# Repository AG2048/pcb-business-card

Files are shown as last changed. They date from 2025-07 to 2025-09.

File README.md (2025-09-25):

# pcb-business-card
Business card made using functional PCBs

Latest Revision: V1 (2025)

# Major Revisions:
## V1 (2025)
- Initial release of the PCB business card design.
- Design functions fully wirelessly, no need for any wired connections during operation. Maintains a slim profile (0.8mm thick PCB, with components on one side only).
- PCB dimensions: 85.6mm x 53.98mm (standard credit card size).
- Qi Wireless charging support -- Utilizes BQ51013B Qi Wireless Power Receiver IC to allow for wireless powering of the PCB business card in 5V 1A.
- NFC Tag support -- Utilizes ST25DV64K NFC Tag to allow for wirelessly programming of the RGB LED Matrix Display, while also allowing users to tap the card on their phone to load my website [andygong.com](https://andygong.com).
- RGB LED Matrix / Array Display -- Utilizes a 6x12 RGB LED Matrix of SK6805-EC15 LEDs to allow for colorful display of patterns that can be controlled by an on-board ATtiny84A microcontroller.
- The QR code on the back of the card can be scanned to load [andygong.com](https://andygong.com) as well.

PCB manufactured by [JLCPCB](https://jlcpcb.com/). Prototype boards assembled by [JLCPCB SMT Assembly Service](https://jlcpcb.com/smt-assembly). Further component sourcing and assembly done by myself.

### Images

#### Renders
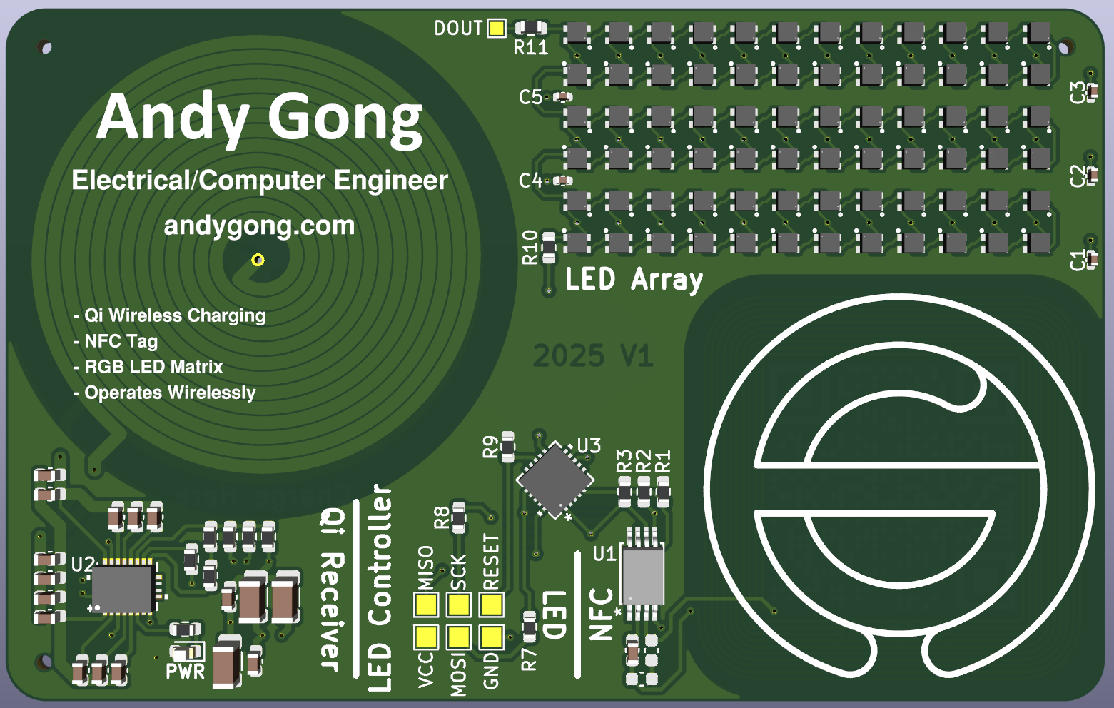
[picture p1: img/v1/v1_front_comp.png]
V1 Front

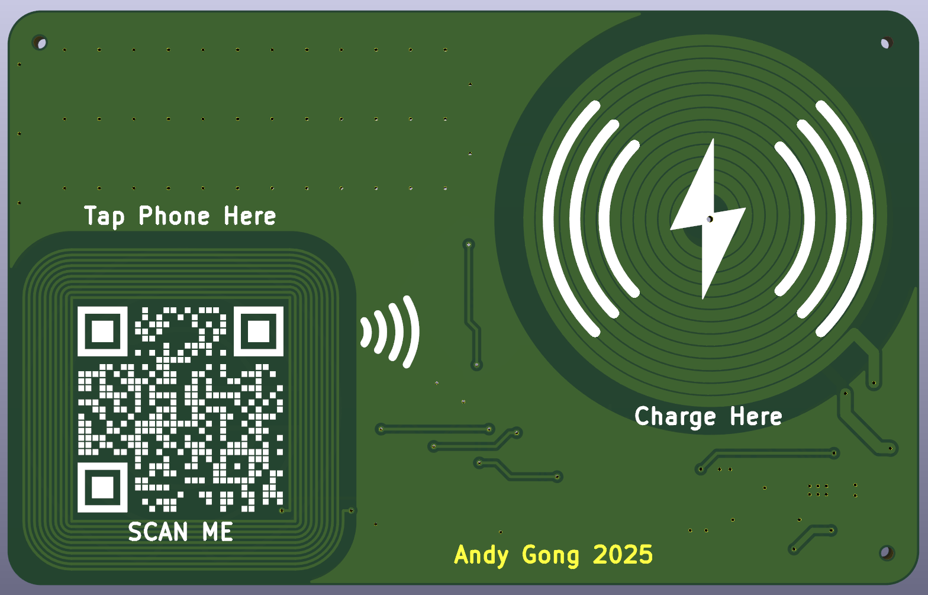
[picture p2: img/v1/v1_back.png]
V1 Back

#### Manufactured Board
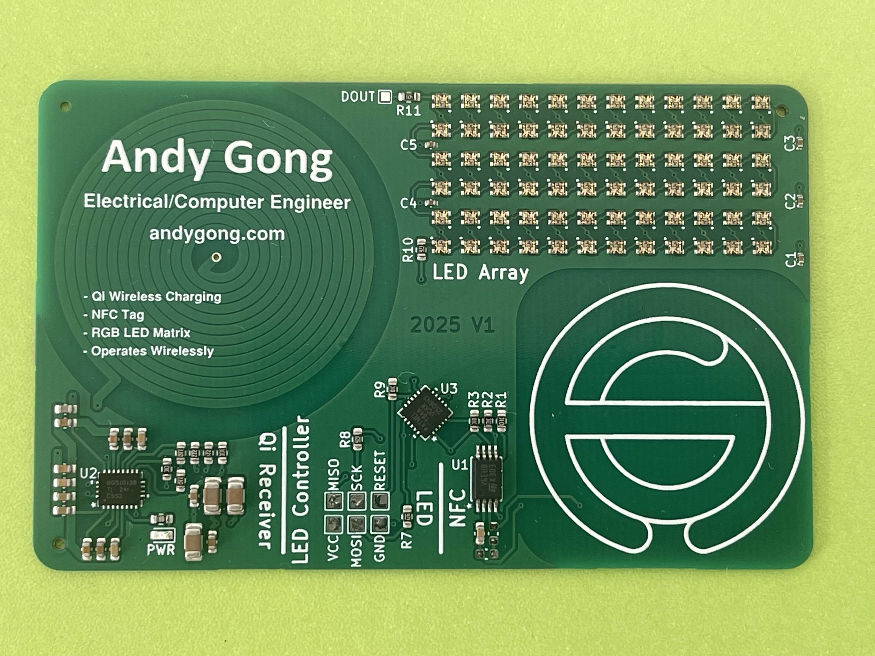
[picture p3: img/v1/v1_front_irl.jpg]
V1 Manufactured Front

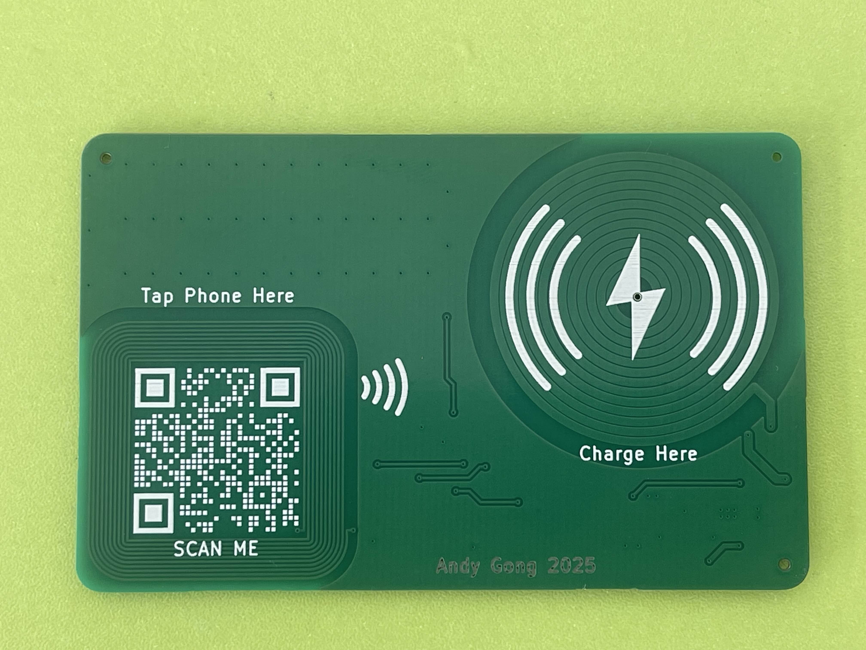
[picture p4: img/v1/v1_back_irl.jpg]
V1 Manufactured Back

#### Early Code Testing
`img/v1/v1_early_test.mov` -- Demonstrates simple patterns on the RGB LED Matrix, with an "Among Us" pixel art pattern shown at the end, which is data sent to the NFC tag by phone, and read by the ATTiny84 using I2C. The code snapshot is [HERE](https://github.com/AG2048/pcb-business-card/commit/e9710af22d912196d3559052da2425deacd2d185)

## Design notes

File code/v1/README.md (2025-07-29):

# V1 Code

This directory contains the code for the AG Business Card V1. This code is to be run on the ATTiny84 microcontroller on the PCB. It reads the ST25DV64K NFC tag for display patterns and displays them on the 6x12 RGB LED matrix.

## Requirements
- ISP Programmer (Used Arduino Uno as ISP)
- [ATTinyCore](https://github.com/SpenceKonde/ATTinyCore)
  - [Wire](https://github.com/SpenceKonde/ATTinyCore/tree/v2.0.0-devThis-is-the-head-submit-PRs-against-this/avr/libraries/Wire) included with ATTinyCore, this allows the use of the hardware I2C on the ATTiny84.
  - [tinyNeoPixel_Static](https://github.com/SpenceKonde/ATTinyCore/tree/v2.0.0-devThis-is-the-head-submit-PRs-against-this/avr/libraries/tinyNeoPixel_Static) for controlling the RGB LED matrix. The static version is used

## Pins
The pinout for ATTiny84 can be found in the [ATTinyCore documentation](https://github.com/SpenceKonde/ATTinyCore/blob/v2.0.0-devThis-is-the-head-submit-PRs-against-this/avr/extras/ATtiny_x4.md). 

The most relevant pin is the LED pin, defined as `LED_PIN` in the code, which is connected to pin 10 of the ATTiny84. This pin is used to control the RGB LED matrix. 

When using the `tinyNeoPixel_Static` library, I configured the bootloader to use PORT B (which is where pin 10 is located). 

The I2C pins uses the standard SDA and SCL pins, so `Wire.begin()` will automatically use the correct pins.

## LED Matrix
The `tinyNeoPixel_Static` library is used to control the RGB LED matrix. This library uses a static array of bytes to store the pixel data in `GRB888` format. The pixels can be modified by setting corresponding values in the `pixel_data` array.

After some preliminary tests, the brightness of each colour of the RGB LEDs is set to be capped at 15 (0xF) to prevent:
1. Excess power draw -- as a "full white" test of max brightness (255) caused the LED matrix to appear red / orange (not enough power supply to light up the green and blue LEDs sufficiently).
2. Excess brightness -- at 255, the LEDs' brightness can be "blinding", and regular phone cameras would likely just capture a "white blur" instead of individual pixels. 

This setup can also save memory. Since a `GRB888` array for 72 pixels takes up 216 bytes out of the total 512 bytes RAM on ATTiny84, and if the brightness is capped at 15 (only 4 bits per channel), the memory requirement can effectively be halved. 

### tinyNeoPixel_Static Modifications
To accomodate a reduced-sized pixels array, the original `tinyNeoPixel_Static` library can no longer be used. 
1. The array now stores GRBGRBGRBGRB... tightly in GRB444 format (Meaning two neighbouring pixels may share bytes)
2. The `show()` function's assembly code is modified to default display `0` for the higher 4 bits. 
   - Adding 4 extra 0 writes in front of bit 7 and bit 3 makes the assembly code too long that the relative jump at the end of each byte write cannot reach the beginning of the program. (64 instructions limit per jump)
   - Broken the code into a write upper bits, write lower bits, and two separate write-zero functions. They are arranged in: WRITE_UPPER -> WRITE_ZERO_TO_LOWER -> WRITE_ZERO_TO_UPPER -> WRITE_LOWER.
   - The program starts the write-zero that jumps to write upper bits. Then it proceeds to the write-zero that jumps to write lower bits. Finally, it jumps back to the write zero that jumps to write upper bits again. The program loops in a sort of "zig-zag" pattern.
   - This breaks the jumps into smaller 50-ish instructions jumps, allowing the assembly code to function within the timing constraints of the LEDs, since there is not a lot of free instructions left to fit every bit write within 10 cycles. 

A custom leds_set_pixel_color function is used to set the pixel color in the `pixel_data` array. This function takes the x and y coordinates of the pixel, and the red, green, and blue values to set the pixel color. This is used because the LEDs are arranged in a zig-zag pattern, so the pixel data needs to be set in a specific order.

## NFC I2C
The ST25DV64K NFC tag is used to store the display patterns for the RGB LED matrix. The NFC tag is accessed using the I2C protocol, and the `Wire` library is used to communicate with the NFC tag.

Currently it is assumed that the NFC tag does not have password protection enabled for wired I2C access.

The ATTiny84 will wait for 500 ms at the start of the program to allow the NFC tag to power up and be ready for communication. This is done using `delay(500)`.

To read the NFC tag, the `nfc_read_data` function is used. This function reads a specified number of bytes from the NFC tag starting at a specified address. The data is stored in the `nfc_data` buffer array.

Inside `nfc_read_data`, we first use `Wire.beginTransmission(NFC_I2C_ADDRESS)` to begin a `WRITE` operation to the NFC tag, where we write the 2-byte address we wish to read from (upper byte first). According to the ST25DV64K datasheet, we need to send a `RESTART` condition and switch to a `READ` operation to read the data from memory. This was done using `Wire.endTransmission(false)` to keep the I2C bus open, and then using `Wire.requestFrom(NFC_I2C_ADDRESS, length)` to read the data from the NFC tag.

`NFC_I2C_ADDRESS` is defined as `0b1010011`, which is the NFC tag's address that accesses the user memory. 

## Pattern Encoding
The NFC tag is supposed to store [andygong.com](https://andygong.com) as its URL readable by tapping the card on a phone. This means that any graphical patterns should start in **byte 32** of the NFC tag memory. When writing to the NFC tag, this is data **block 8**. 

72 pixels of 1.5 bytes each (in `GRB444` format) uses 108 bytes for pixel data. Meaning that out of 8 kB of user memory, we can store 75 frames as a maximum. 

Each frame should have some metadata:
- Colour mode -- as in if each bit of data represent a single pixel, or the data is in `GRB444` format.
  - Single pixel mode only requires 1 bit per pixel, so 9 bytes for 72 pixels. (A default colour value can be set for the entire frame, such as red, green, blue, orange, yellow... etc.)
  - `GRB444` format requires 1.5 bytes per pixel, so 108 bytes for 72 pixels.
  - This can be set by using 3 bits (`000` for `GRB444` mode, and the rest are for `GRB` combinations for single pixel mode, such as `001` is for blue, `110` is for green+red=yellow, etc.)
- Transition format
  - If the frame is instantly changed from previous frame
  - If the frame "fades" from previous frame
  - This will be set using 13 bits, representing the transition time in milliseconds. (This can be set to 0 for instant change, or a value between 1 and 8191 milliseconds for a fade transition.)
- Frame duration -- how long the frame should be displayed for, in milliseconds.
  - This will use 2 bytes (16 bits) for up to 65,535 milliseconds (or 65.535 seconds) of display time.

Overall, each frame will have 4 bytes of metadata (`CCCT_TTTT_TTTT_TTTT_DDDD_DDDD_DDDD_DDDD`), where:
- `CCC` is the colour mode (3 bits)
- `T_TTTT_TTTT_TTTT` is the transition time (13 bits)
- `DDDD_DDDD_DDDD_DDDD` is the frame duration (16 bits)

This aligns with the 32-bit word size of the NFC tag.

With the metadata, each frame will have a minimum of `4+9=13` bytes for single pixel mode, or `4+108=112` bytes for `GRB444` mode. So we can fit a minimum of 72 frames to a maximum of 627 frames. 

The first few bytes should store some data about the overall storage. Such as:
- The number of images/frames stored in the NFC tag -- so that the code knows when to stop reading. 
  - This uses 2 bytes as maximum is 627 > 255 for 1 byte storage. 
- The remaining 2 bytes can be used for a delay in milliseconds before the first frame is displayed, since the first frame's "Transition Time" can only be used as a "fade-in" effect from black, and it cannot be used for a "pure delay" unlike the "Frame Duration" value.

Overall, the first 4 bytes of the NFC tag should be:
`NNNN_NNNN_FFFF_FFFF`
Where:
- `NNNN_NNNN` is the number of frames stored (8 bits)
- `FFFF_FFFF` is the delay before the first frame (32 bits)

## Code Flow
The code proceeds as follows:
1. Initialize
  - Set memory address to `NFC_FIRST_ADDRESS` (32, block 8)
  - Read `NNNN_NNNN` and `FFFF_FFFF` from the NFC tag to get the number of frames and the initial delay.
  - Wait for the initial delay before displaying the first frame.
2. Load frame data
  - Read `CCC`, `T_TTTT_TTTT_TTTT`, and `DDDD_DDDD_DDDD_DDDD` from the NFC tag to get the colour mode, transition time, and frame duration.
  - If colour mode is `GRB444` (`CCC == 000`) display in `GRB444` mode.
  - If colour mode is single pixel mode, display in single pixel mode.
3. Display frame
  - `GRB444` mode:
    - Read `PIXEL_ARRAY_SIZE` bytes from the NFC tag, starting from the current address.
    - Use `nfc_data` as a buffer for the next frame.
    - Handle transition and display. 
    - Wait for frame duration.
  - Single pixel mode:
    - Read `NUM_PIXELS_IN_BYTES` bytes from the NFC tag, starting from the current address.
    - Depending on which bit in `CCC` is set, set that channel's colour to `MAX_BRIGHTNESS`. Else set to `0`. 
    - Based on each bit is `1` or `0`, fill each pixel by 0 or the colours. 
    - Use `nfc_data` as a buffer for the next frame.
    - Handle transition and display.
    - Wait for frame duration.
4. Handle transition
  - If the transition time is `0`, display the next frame immediately (prevent divide by 0 errors).
  - If the transition time is greater than `0`, fade from the current frame to the next frame over the specified transition time.
  - Store original frame in `original_pixel_data` array. 
  - Every 16 ms, calculate the "gap" between pixel values, and interpolate pixel values based on elapsed time and transition time.
  - Update pixel data in `pixel_data` array and display the frame.
  - At the end, copy the entire `nfc_data` to `pixel_data` to complete the transition.
5. Repeat
  - Repeat 2-4 until all frames from `NNNN_NNNN` have been displayed.
  - Repeat step 1. 

During this time, if any error occurs (most likely NFC I2C read error), the code will flash a full-red screen with no delay. The program restarts from initialization. This is done to prevent address overflowing / wrapping on an uninitialized NFC memory. 

## Function / Variable / Define Documentation
Note: all pins are using the default clockwise pin numbering from `ATTinyCore`. 
### Hardware Configuration
#### `#define LED_PIN`
The pin number for the RGB LED matrix. This is connected to pin 10 of the ATTiny84.
#### `#define LED_ROWS`
The number of rows in the RGB LED matrix. This is set to 6 for the 6x12 matrix.
#### `#define LED_COLS`
The number of columns in the RGB LED matrix. This is set to 12 for the 6x12 matrix.
#### `#define I2C_SDA`
The I2C SDA pin number. This is connected to pin 6 of the ATTiny84.
#### `#define I2C_SCL`
The I2C SCL pin number. This is connected to pin 4 of the ATTiny84.
#### `#define NFC_GPO`
The NFC GPO pin number. This is connected to pin 0 of the ATTiny84.
#### `#define NFC_FIRST_ADDRESS`
The first address in the NFC tag to read from. This is set to 32, which is block 8 in the ST25DV64K NFC tag memory. This is where the pixel data starts.
#### `#define NFC_MAX_POSSIBLE_FRAMES`
The maximum number of frames that can be stored in the NFC tag. This is set to 627, which is the maximum number of frames that can be stored in the NFC tag with the current metadata format. This is currently not used. 
### LED Matrix
#### `#define LED_COUNT`
The number of LEDs in the RGB LED matrix. This is set to 72 (`LED_ROWS * LED_COLS`).
#### `#define MAX_BRIGHTNESS`
The maximum brightness value for each colour channel in the RGB LED matrix. This is set to 15 (0xF) to prevent excess power draw and brightness.
#### `#define PIXEL_ARRAY_SIZE`
The size of the pixel array in bytes for `GRB444` mode. This is set to `LED_COUNT * 1.5`, which is 108 bytes for 72 pixels, since each pixel takes up 12 bits in `GRB444` format.
#### `#define NUM_PIXELS_IN_BYTES`
The number of pixels divided by 8. This is used to calculate the size of a buffer required to store bytes that represent the on/off state of each pixel for each bit of data.
#### `byte pixel_data[PIXEL_ARRAY_SIZE]`
The pixel data array that stores the `GRB444` pixel data for the RGB LED matrix. This is a static array of bytes that is used to store the pixel data for the current frame. The `leds_show()` function uses this static array to write data to the RGB LED matrix.
#### `uint32_t endTime`
The end time when the previous frame was finished displaying. This is used to determine if sufficient time has passed since the last frame's data was sent, enough for the reset time to register on the LEDs. The value is set to `micros()` at the end of each `leds_show()` call, and the `leds_show()` function will wait until `micros() - endTime` is greater than or equal to `50L` before proceeding to the next frame.
#### `uint8_t p = LED_PIN`
The pin number for the LEDs. This is used by `digitalPinToPort()` and `digitalPinToBitMask()` to get the `port` and `pinMask` for the LED pin. 
#### `volatile uint8_t *port`
Pointer to the port output register for the LED pin. This is used in assembly code to directly write to the output port for faster performance.
#### `uint8_t pinMask`
The bit mask for the LED output pin. This is used to set `hi` and `lo` values to set the output pin high or low in the assembly code.

WIP, TODO. 

## Generate NFC Binary
The `generate_nfc_binary.py` script is used to generate the binary file that can be written to the NFC tag to be displayed.
It takes a list of images or GIFs, and associated colour and timing data, and generates a hex binary file for the NFC tag.

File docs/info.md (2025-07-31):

# PCB Business Card Development Procedures and Resources
This document provides the documentation and resources for my PCB business card project.

An overview of the project's major components discusses the research and considerations made for the Qi charging, NFC tag, processor, and LED matrix. 

This document then describes the creation and testing of the Qi and NFC test board prior to the V1 board. 

The V1 board design and improvements based on the test board are then discussed, as well as the software development involved to drive the display and read data wirelessly transmitted to the NFC tag. 

## Individual Components Research
The PCB business card consists of several key components / features. This section describes the research, design process, and resources for each component.

### Qi Charging
The first feature I wanted to implement on the PCB business card is a way to wirelessly charge the card using a coil etched on the PCB itself. 

Before any design was made, I was facing two possible choices:
1. Make a PCB that is mostly designed for the look and aethetics of a business card, where copper traces and exposed copper areas are used to form patterns and shapes that does not have a lot of (if any) functional purpose. A card like this would obviously look very nice, but it may not be functional and therefore may not be able to demonstrate my skills / capabilities as a computer / electrical engineer. 
2. Make a PCB that is functional and can be an electronic display to the user using actuators (data processing PCBs are not very interesting to look at, and the tools / devices used to drive such data processors can be hard to demonstrate outside of a familiar environment). This would allow me to demonstrate and develop my PCB design skills, but could make the board less visually appealing.

I ended up choosing the second option, since I wanted something that is functional, instead of just being a pretty piece of fibre / copper. 

From what I have seen in other PCB business cards that can be found online, most of them require wired power / signal transmission to the business card (if those business card is functional at all). However, any type of connector would inevitably make the card thicker, while exposed 5V/GND wires and pads would mean that I have to carry a specific DC power supply that can supply power to wires and then onto the card. 

With those considerations in mind, I decided that a wireless power solution using PCB coils would be the best idea. It would look nice and unique (PCB coils are not very common overall), maintain a thin profile for the card (no additional connectors are needed to power the card, the coil would also have to be etched on the PCB itself, as any external coils would add to the card's thickness), and it is overall a new and interesting design I have not worked on before.

#### Existing Wireless Power PCBs
Doing some research online, I came across a YouTube video that designed a simple wireless power transfer PCB using two boards with PCB coils. 

[How to make Wireless Power Transmitter With printed Coil on the PCB](https://youtu.be/3QEGdm6vfUw?si=p93Ei830A4B2cbgJ)

The design is simple. It involves a source PCB with an LC circuit that is driven on and off by a 555 timer, which generates a square wave that is then transmitted to the receiver PCB with a corresponding LC circuit. The receiver can then connect the LC circuit to a rectifier to convert the AC signal in the coils back to DC, which can then be used to power a load.

In this video, the key is to tune the inductance and the capacitance of the LC circuits such that their resonant frequency matches the frequency of the switching network (generated by the 555 timer). This allows efficient power transfer, or else the receiver may not receive enough power to drive the load. However, this video also showed that the inductance of the PCB coils should be determined after the PCB is manufactured, and any capacitors should be selected accordingly after measuring the PCB coils' inductance. This can become challenging as I intend to use only SMD components on the PCB to keep it thin, and it would be difficult to predict what combination of capacitors (series / parallel) would be needed to match the resonant frequency of the PCB coils, meaning that I cannot produce a fully functional board before finding out what capacitance is needed. Furthermore, the PCB manufacturer I was using (JLCPCB) is located in China, which means that I would have to wait a long time and pay for shipping just for an early prototype of the wireless power module. 

This video provided me a good foundation and understanding of wireless power using PCB coils, and proved that this idea is, at minimum, possible. However, it is also mentioned that this form of power transfer is not very efficient, and specific protocols might be needed to send sufficient power to the receiver. Additionally, this design does not solve my initial concern of requiring a specific DC power supply, it simply shifted the problem from the PCB card itself to a separate PCB that is used as the transmitter. I hope that I can charge / power the PCB business card with a standard wireless charger that is relatively common nowadays for smartphones, so that I can provide power to the card using any wireless charger, and that other people who receives my card can also charge / power the card using their own wireless chargers.

#### Qi Wireless Charging
From my knowledge, a popular wireless charging standard is the Qi standard, and thus I began looking into how Qi wireless charging works, and if it is possible to implement this protocol on a small PCB. 

The first resource I found is this blog: [Qi wireless power receiver from scratch](https://blog.vinu.co.in/2019/04/qi-wireless-power-receiver-from-scratch.html). This blog outlines the basic principles of the Qi wireless charging protocol (did you know that Qi allows communications between the transmitter and the receiver in binary?) and provides a simple implementation of a Qi receiver driven by an ATTiny13A microcontroller. This implementation is very simple, as from reading the [source code](https://github.com/vinodstanur/qi_wireless_receiver_attiny13), it only pings the transmitter once receiving power, and then periodically request more or less power based on an analog pin input. Even though the implementation is simple, it is still a good starting point for me to understand how the Qi protocol works and how I can implement it myself on my PCB. 

After reading the blog, I went to the WPC (Wireless Power Consortium) website to read the official Qi specification. As it turned out, there's much more communication and specifications that a proper Qi receiver needs to implement. Therefore, I gave up trying to implement my own Qi receiver, and instead looked for existing power receiver ICs that I can use to drive the Qi receiver, while I still design the PCB coil myself. (From reading the Qi specification, I have set my initial target coil size to around 4 cm in diameter, since that is the recommended size mentioned for a Qi receiver)

#### Wireless Charger Design
- Looking for chip (that can be PCBA by JLC)
- Understanding L and L' values
- Online PCB coil calculators.
- Q factor matching -- custom Desmos script
  - Here considering between 1 oz vs 2 oz copper, which reduces R so boosts Q...
  - Cost issue...
  - manufacturer minimum spacing
  - Surprisingly, decreasing L but replacing to MUCH thicker traces can increase Q.
  - Single vs double layer coil -- mutual inductance calculation. (paper)
- I cannot personally test the board, left footprints for any 3C combination of caps. Also left TPs for through hole caps / wires. 
(More details in the Qi and NFC Test Board section)

### NFC Tag
- Initially I wanted to drive the LEDs using the microcontroller itself, with shift registers to read signals from the microprocessor's limited pins, and do a "row by row" scan of the LED matrix to basically display the whole matrix with a 1/N duty cycle.  
- To use the limited pins on microprocessors, I thought about using an 8-bit data output EEPROM that can read an address stored on shift register, and display corresponding "column pattern" when the corresponding row is turned on. 
- Through my search, I found EEPROMs that uses I2C to read / write data. This is not very ideal with my initial design, since it would require multiple cycles to let the module output data, and the data is shown through the I2C bus instead of the parallel bus I was looking for. But this gave me an idea to use such EEPROM to temporarily load patterns onto the chip memory, and "shift" the data out to the LED matrix in a "longer" shift register chain that handles both rows and columns. 
- At this point, I had planned 2 pins for Shift register control and 2 for I2C. But clearly the initial ATTiny10 idea doesn't have enough pins for this. Had to compromise by also shifting the I2C "clock" signal through shift registers, only leaving the SDA pin as an IO pin directly to the processor... Clearly, this isn't a great solution...
- While looking for inspirations from existing PCB business cards, I found that a lot of cards have NFC tags that can display their websites when tapped by a phone. I then realized through some search of existing NFC tag chips that a lot of such NFC tags have large user memory areas that can double as a data storage EEPROM for the LED matrix. Better yet, they are also I2C compatible. 
- Another benefit on top of that is that these NFC tags can be written to by a phone. So in this case, as long as the microcontroller's program can read the NFC tag's user memory, I can remotely update any display patterns on the card. This would be a great addition to the card, since not only it is "cool" (as in it's wireless), it is also very convenient and practical, since if I had used a regular EEPROM, any pattern change would require some wired re-programming of the EEPROM. But now I can just tap my phone on it with the images (although it has to be formatted correctly) and everything is done. 

- Go into coil design -- the NFC tag has a standard built-in capacitance. Therefore only the inductor coil needs to be designed. However, I'm personally worried about the coil being next to wireless power (the Qi charger). So according to ST's recommendations, I added a seires 1nF capacitor to act as a high-pass filter to block the 100kHz Qi signal, while allowing the NFC tag's 13.56 MHz signal to pass through.
- Also from some development recommendations, I made the coils' inductances SLIGHTLY smaller than what's needed -- so it can be compendated by adding parallel capacitors to tune the resonant frequency -- while reducing the capacitance may need more work. 

### Processor
- Was previously working with ATTiny10 on some other projects
- Realized ATTinys are pretty good processors for small projects. 
- Initially considered ATTiny10, but it doesn't have enough RAM and pins for an initial shift register type LED matrix. 
- Thought about ATTiny20, but there's not a lot of support / resources online for programming / programmer...
- Switched to the more popular ATTiny84. It has enough pins (enough to support my initial shifting register LED matrix design). It has enough memory (512 B is a lot for my application -- at least when every pixel is just 1 bit). 

### LED Matrix
- Hoped for a 8x16 matrix, arranged like the Arduino Uno R4 matrix.
- Alluded to before, thought of a matrix similar to that of Arduino Uno R4. I don't want to deal with charlieplexing. So I thought about a row by row scanning...
- Found some TI shift registers (open drain and push-pull / 3 state...) that can be used. 
- However, after finding some existing PCB business card with LED matrix, I realized that I could just use a small 1mm x 1mm addressable RGB LED matrix. (I initially thought about addressible LEDs, but my early searches all ended up with those LARGE LEDs, so I kinda gave up too early on that)
- Since in this case, I would like JLC to handle the PCB assembly. I found the closest one on their website with is a 1.5mm x 1.5mm LED, which is unfortunate that I can only fit 6x12 of those on the PCB. Additionally, those LEDs only need 1 pin to drive. 
- I was initially scared by their recommendations on the datasheet that EVERY LED should have its own capacitor between VCC and GND (not enough space...)... But later I realized it's probably fine as long as the power is stable / there's enough capacitors close enough between multiple LEDs.
- In V2 board, I found some alternative 1mm x 1mm LEDs that are also cheaper. So hopefully I can fit an 8x16 matrix on the V2 board. Honestly 8x12 also looks fine.
- Was worried about power consumptions. But from V1 board tests, full brightness is TOO bright, so running only at 1/16 brightness. (The power can barely support 72 LEDs' at full brightness, but 1/16 brightness is definitely fine... So I think expanding to 8x16 is ok on the power side.)

## Qi and NFC Test Board

## V1 Board

### Code Development
- Made simple LED demo -- too bright... reduced brightness to 1/16
- This also saved memory, but didn't do anything about it just yet.
- Tested it with NFC tag, it can read some bytes from NFC tag and recognize it as bit pattern for LED matrix and display it.
- Then modified the code to read structured data from NFC tag that can display a "gif" / fade in, fade out, long duration... etc
- Modified the LED display code, to automatically write zeros to upper 4 bits of each pixel channel. Modified assembly since directly adding 4 zero writes is too long for the assembly to rjmp. 
- Realized default, I made the NFC tag read too much data at once, now reducing to only read 30 bytes at a time. (limited by size of buffer in Wire.h library for ATTinyCore)

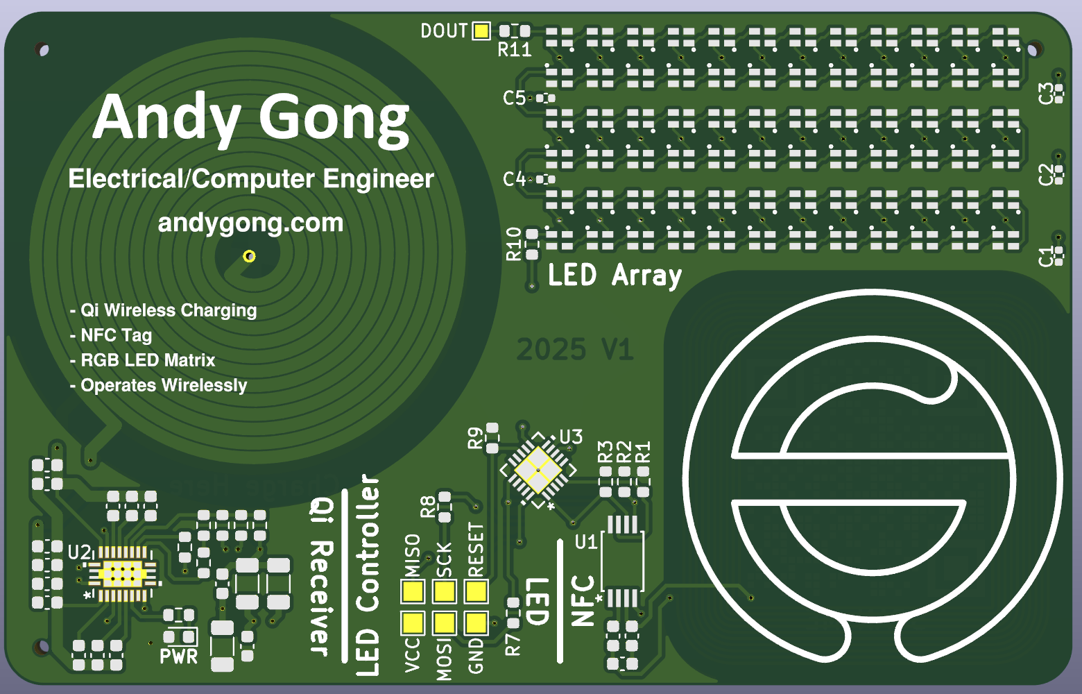
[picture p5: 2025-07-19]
img/v1/v1_front_nocomp.png

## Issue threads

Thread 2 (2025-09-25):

Single-Color Mode Doesn't Work

AG2048, 2025-09-25:
Currently, single-color mode with no transition time doesn't work at all, it's empty frame. And with transition time, it's the wrong pattern.

Closed 2025-09-25.

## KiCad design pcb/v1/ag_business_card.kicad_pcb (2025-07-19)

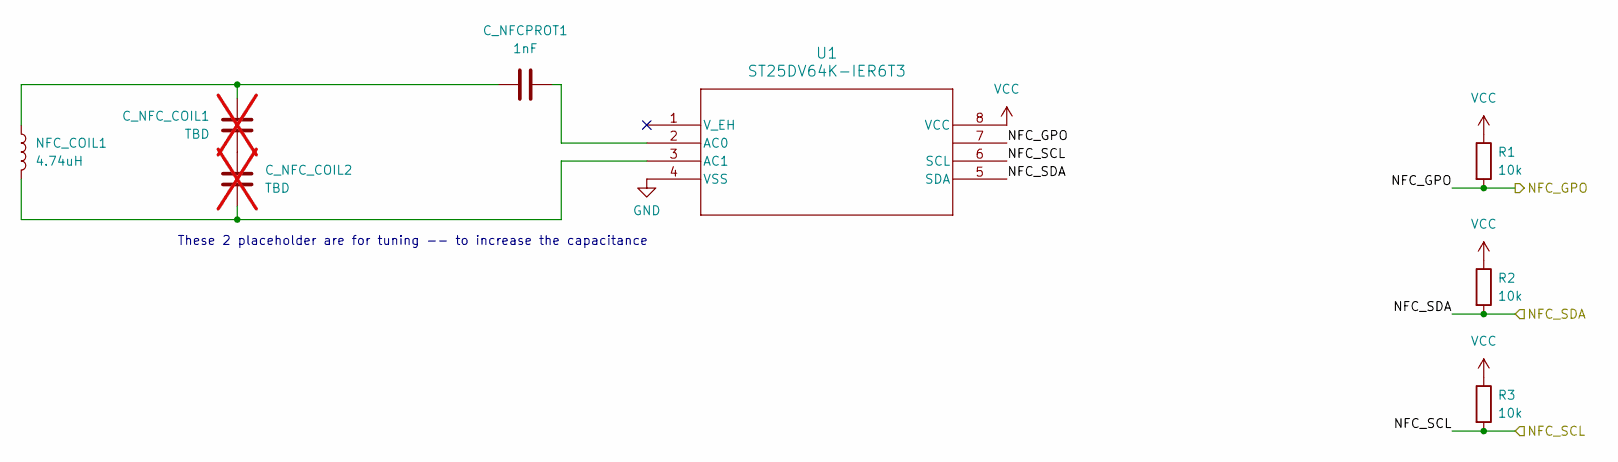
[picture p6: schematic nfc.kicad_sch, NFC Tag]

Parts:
C_NFCPROT1: 1nF; C_0603_1608Metric
C_NFC_COIL1, C_NFC_COIL2: TBD; C_0603_1608Metric; not fitted
NFC_COIL1: 4.74uH; NFC_COIL_4.74uH
R1, R2, R3: 10k; R_0603_1608Metric
U1: ST25DV64K-IER6T3; TSSOP_V64K-IER6T3_STM

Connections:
/NFC/NFC_GPO: R1.2, U1.7; also elsewhere on the board
/NFC/NFC_SCL: R3.2, U1.6 (SCL); also elsewhere on the board
/NFC/NFC_SDA: R2.2, U1.5 (SDA); also elsewhere on the board
GND: U1.4 (VSS); also elsewhere on the board
unnamed: C_NFCPROT1.2, C_NFC_COIL1.2, NFC_COIL1.1
unnamed: C_NFC_COIL1.1, C_NFC_COIL2.2
unnamed: C_NFCPROT1.1, U1.2 (AC0)
unnamed: C_NFC_COIL2.1, NFC_COIL1.2, U1.3 (AC1)
VCC: R1.1, R2.1, R3.1, U1.8 (VCC); also elsewhere on the board

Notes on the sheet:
These 2 placeholder are for tuning -- to increase the capacitance

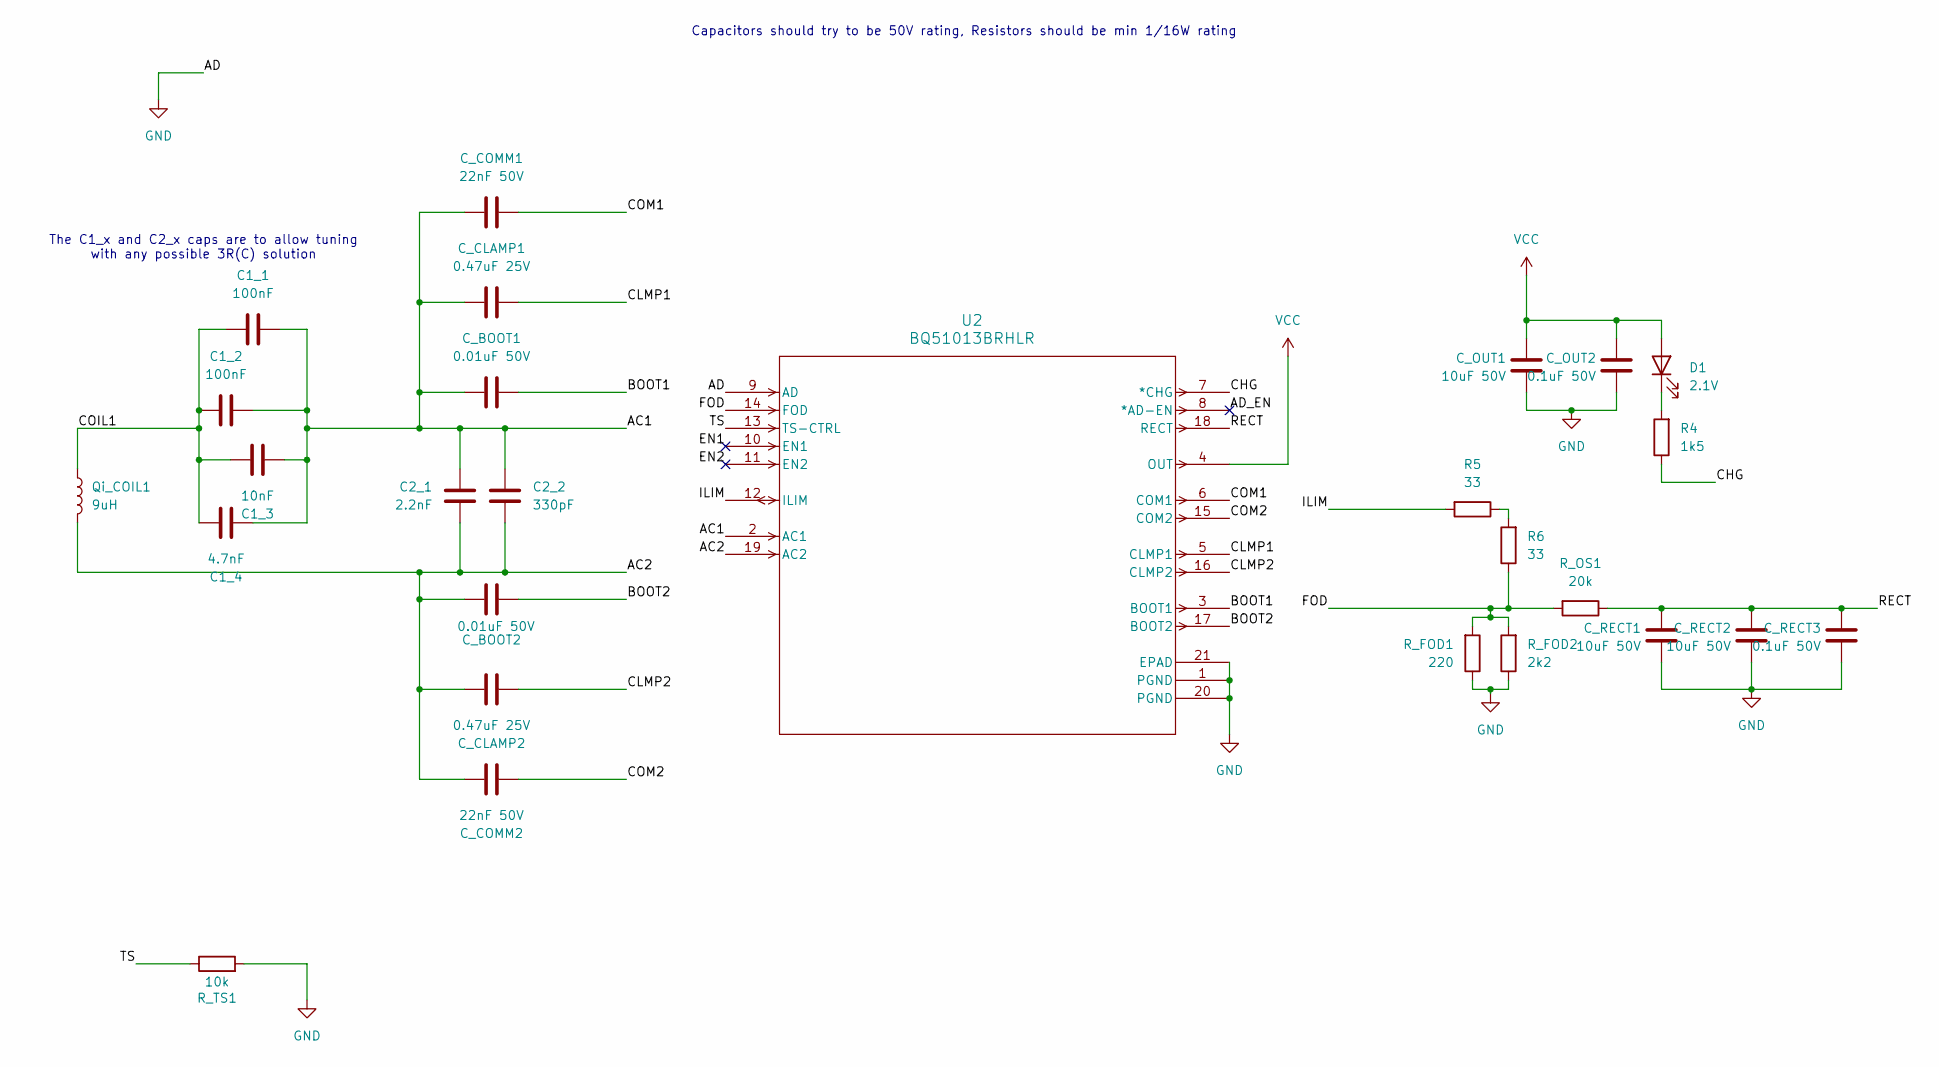
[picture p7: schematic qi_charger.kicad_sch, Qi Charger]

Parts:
C1_1, C1_2: 100nF; C_0603_1608Metric
C1_3: 10nF; C_0603_1608Metric
C1_4: 4.7nF; C_0603_1608Metric
C2_1: 2.2nF; C_0603_1608Metric
C2_2: 330pF; C_0603_1608Metric
C_BOOT1, C_BOOT2: 0.01uF 50V; C_0603_1608Metric
C_CLAMP1, C_CLAMP2: 0.47uF 25V; C_0603_1608Metric
C_COMM1, C_COMM2: 22nF 50V; C_0603_1608Metric
C_OUT1: 10uF 50V; C_1206_3216Metric
C_OUT2: 0.1uF 50V; C_0603_1608Metric
C_RECT1, C_RECT2: 10uF 50V; C_1206_3216Metric
C_RECT3: 0.1uF 50V; C_0603_1608Metric
D1: 2.1V; LED_0603_1608Metric
Qi_COIL1: 9uH; Qi_COIL_9uH_2_layer
R4: 1k5; R_0603_1608Metric
R5, R6: 33; R_0603_1608Metric
R_FOD1: 220; R_0603_1608Metric
R_FOD2: 2k2; R_0603_1608Metric
R_OS1: 20k; R_0603_1608Metric
R_TS1: 10k; R_0603_1608Metric
U2: BQ51013BRHLR; RHL20_2P05X3P05

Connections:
/Qi Charger/AC1: C1_1.1, C1_2.1, C1_3.1, C1_4.1, C2_1.2, C2_2.2, C_BOOT1.2, C_CLAMP1.2, C_COMM1.2, U2.2 (AC1)
/Qi Charger/AC2: C2_1.1, C2_2.1, C_BOOT2.1, C_CLAMP2.1, C_COMM2.1, Qi_COIL1.2, U2.19 (AC2)
/Qi Charger/AD_EN: U2.8 (*AD-EN)
/Qi Charger/BOOT1: C_BOOT1.1, U2.3 (BOOT1)
/Qi Charger/BOOT2: C_BOOT2.2, U2.17 (BOOT2)
/Qi Charger/CHG: R4.1, U2.7 (*CHG)
/Qi Charger/CLMP1: C_CLAMP1.1, U2.5 (CLMP1)
/Qi Charger/CLMP2: C_CLAMP2.2, U2.16 (CLMP2)
/Qi Charger/COIL1: C1_1.2, C1_2.2, C1_3.2, C1_4.2, Qi_COIL1.1
/Qi Charger/COM1: C_COMM1.1, U2.6 (COM1)
/Qi Charger/COM2: C_COMM2.2, U2.15 (COM2)
/Qi Charger/EN1: U2.10 (EN1)
/Qi Charger/EN2: U2.11 (EN2)
/Qi Charger/FOD: R6.1, R_FOD1.2, R_FOD2.2, R_OS1.2, U2.14 (FOD)
/Qi Charger/ILIM: R5.2, U2.12 (ILIM)
/Qi Charger/RECT: C_RECT1.2, C_RECT2.2, C_RECT3.2, R_OS1.1, U2.18 (RECT)
/Qi Charger/TS: R_TS1.1, U2.13 (TS-CTRL)
GND: C_OUT1.1, C_OUT2.1, C_RECT1.1, C_RECT2.1, C_RECT3.1, R_FOD1.1, R_FOD2.1, R_TS1.2, U2.1 (PGND), U2.9 (AD), U2.20 (PGND), U2.21 (EPAD); also elsewhere on the board
unnamed: D1.1 (K), R4.2
unnamed: R5.1, R6.2
VCC: C_OUT1.2, C_OUT2.2, D1.2 (A), U2.4 (OUT); also elsewhere on the board

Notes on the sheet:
Capacitors should try to be 50V rating, Resistors should be min 1/16W rating
The C1_x and C2_x caps are to allow tuning with any possible 3R(C) solution

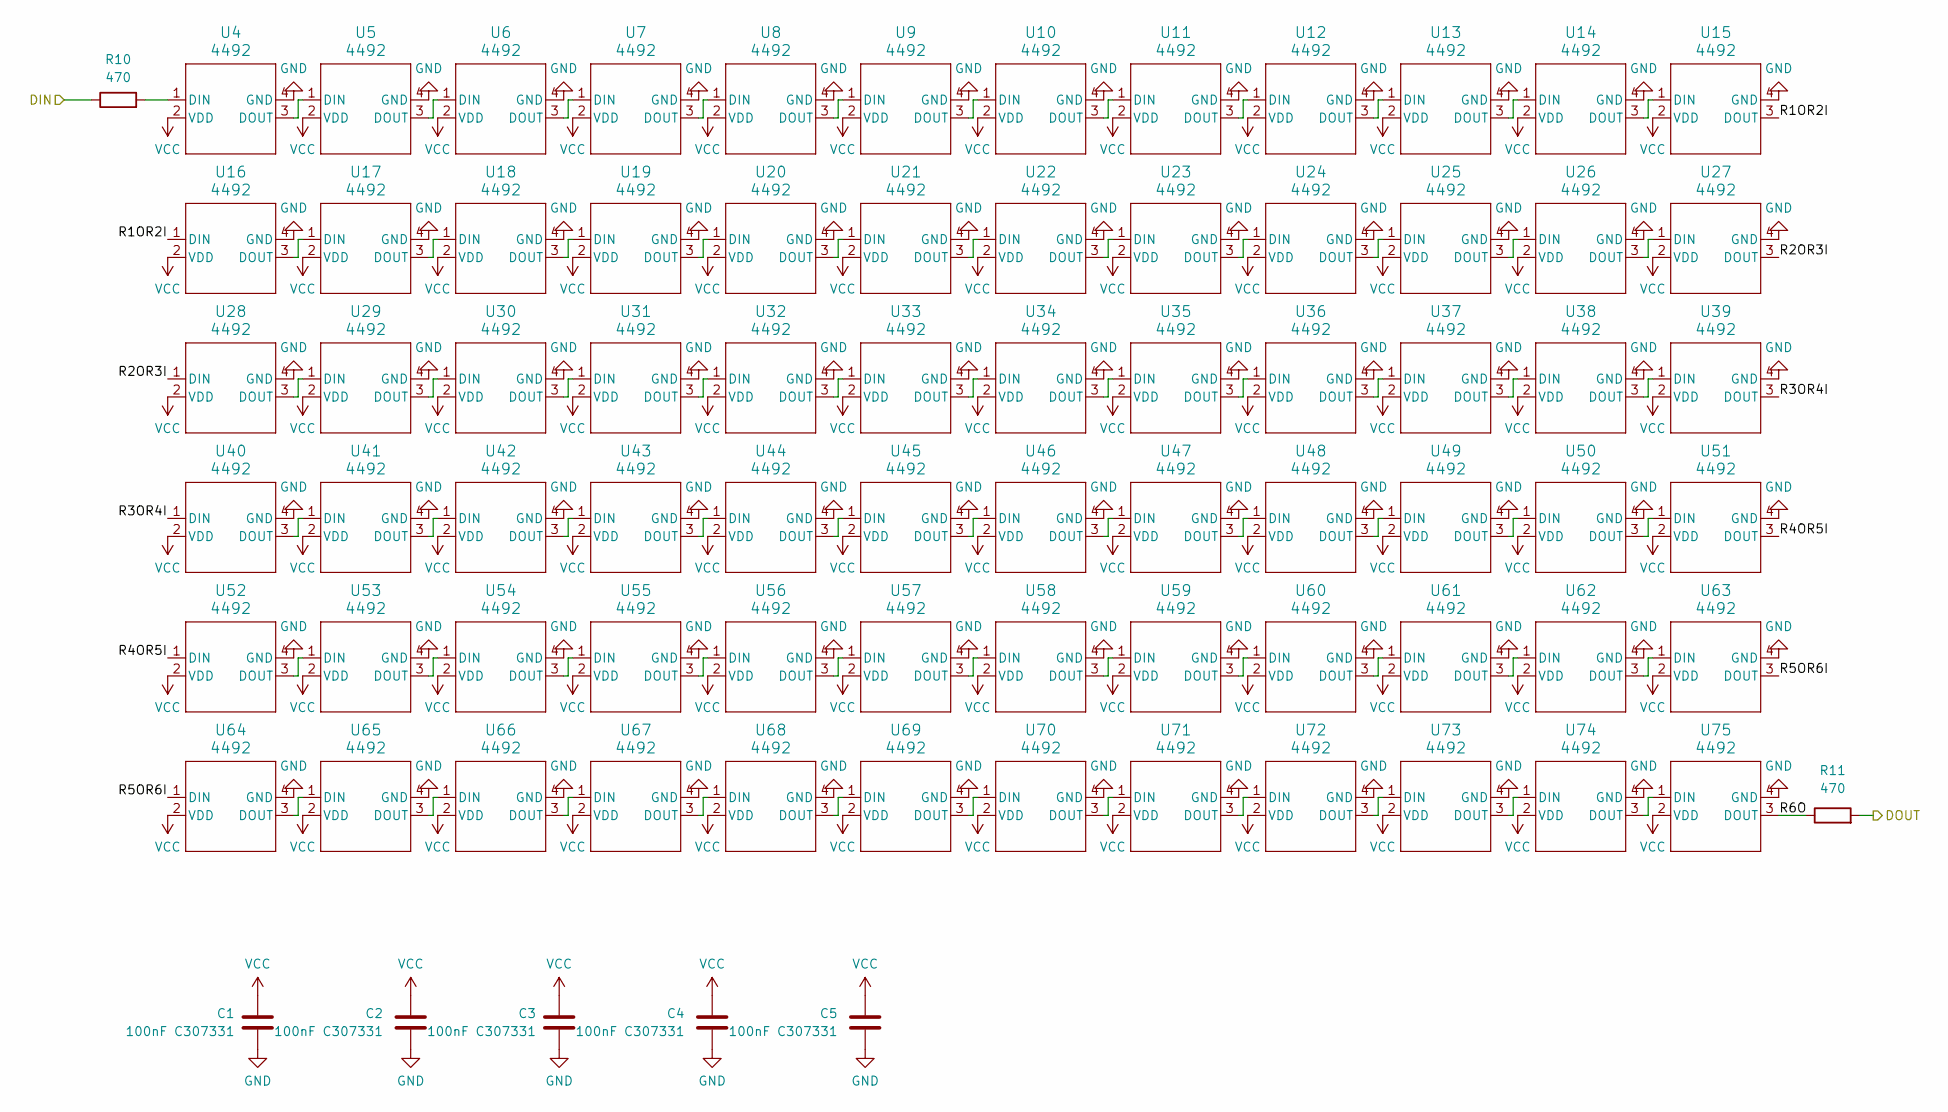
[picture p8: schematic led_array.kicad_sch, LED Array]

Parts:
C1, C2, C3, C4, C5: 100nF C307331; C_0402_1005Metric
R10, R11: 470; R_0603_1608Metric
U4, U5, U6, U7, U8, U9, U10, U11, U12, U13, U14, U15, U16, U17, U18, U19, U20, U21, U22, U23, U24, U25, U26, U27, U28, U29, U30, U31, U32, U33, U34, U35, U36, U37, U38, U39, U40, U41, U42, U43, U44, U45, U46, U47, U48, U49, U50, U51, U52, U53, U54, U55, U56, U57, U58, U59, U60, U61, U62, U63, U64, U65, U66, U67, U68, U69, U70, U71, U72, U73, U74, U75: 4492; 4492_ADA

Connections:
/Display/LED Array/DOUT: R11.2; also elsewhere on the board
/Display/LED Array/R1OR2I: U15.3 (DOUT), U16.1 (DIN)
/Display/LED Array/R2OR3I: U27.3 (DOUT), U28.1 (DIN)
/Display/LED Array/R3OR4I: U39.3 (DOUT), U40.1 (DIN)
/Display/LED Array/R4OR5I: U51.3 (DOUT), U52.1 (DIN)
/Display/LED Array/R5OR6I: U63.3 (DOUT), U64.1 (DIN)
/Display/LED Array/R6O: R11.1, U75.3 (DOUT)
/Display/Processor/LED: R10.1; also elsewhere on the board
GND: C1.1, C2.1, C3.1, C4.1, C5.2, U4.4 (GND), U5.4 (GND), U6.4 (GND), U7.4 (GND), U8.4 (GND), U9.4 (GND), U10.4 (GND), U11.4 (GND), U12.4 (GND), U13.4 (GND), U14.4 (GND), U15.4 (GND), U16.4 (GND), U17.4 (GND), U18.4 (GND), U19.4 (GND), U20.4 (GND), U21.4 (GND), U22.4 (GND), U23.4 (GND), U24.4 (GND), U25.4 (GND), U26.4 (GND), U27.4 (GND), U28.4 (GND), U29.4 (GND), U30.4 (GND), U31.4 (GND), U32.4 (GND), U33.4 (GND), U34.4 (GND), U35.4 (GND), U36.4 (GND), U37.4 (GND), U38.4 (GND), U39.4 (GND), U40.4 (GND), U41.4 (GND), U42.4 (GND), U43.4 (GND), U44.4 (GND), U45.4 (GND), U46.4 (GND), U47.4 (GND), U48.4 (GND), U49.4 (GND), U50.4 (GND), U51.4 (GND), U52.4 (GND), U53.4 (GND), U54.4 (GND), U55.4 (GND), U56.4 (GND), U57.4 (GND), U58.4 (GND), U59.4 (GND), U60.4 (GND), U61.4 (GND), U62.4 (GND), U63.4 (GND), U64.4 (GND), U65.4 (GND), U66.4 (GND), U67.4 (GND), U68.4 (GND), U69.4 (GND), U70.4 (GND), U71.4 (GND), U72.4 (GND), U73.4 (GND), U74.4 (GND), U75.4 (GND); also elsewhere on the board
unnamed: R10.2, U4.1 (DIN)
unnamed: U4.3 (DOUT), U5.1 (DIN)
unnamed: U5.3 (DOUT), U6.1 (DIN)
unnamed: U6.3 (DOUT), U7.1 (DIN)
unnamed: U7.3 (DOUT), U8.1 (DIN)
unnamed: U8.3 (DOUT), U9.1 (DIN)
unnamed: U9.3 (DOUT), U10.1 (DIN)
unnamed: U10.3 (DOUT), U11.1 (DIN)
unnamed: U11.3 (DOUT), U12.1 (DIN)
unnamed: U12.3 (DOUT), U13.1 (DIN)
unnamed: U13.3 (DOUT), U14.1 (DIN)
unnamed: U14.3 (DOUT), U15.1 (DIN)
unnamed: U16.3 (DOUT), U17.1 (DIN)
unnamed: U17.3 (DOUT), U18.1 (DIN)
unnamed: U18.3 (DOUT), U19.1 (DIN)
unnamed: U19.3 (DOUT), U20.1 (DIN)
unnamed: U20.3 (DOUT), U21.1 (DIN)
unnamed: U21.3 (DOUT), U22.1 (DIN)
unnamed: U22.3 (DOUT), U23.1 (DIN)
unnamed: U23.3 (DOUT), U24.1 (DIN)
unnamed: U24.3 (DOUT), U25.1 (DIN)
unnamed: U25.3 (DOUT), U26.1 (DIN)
unnamed: U26.3 (DOUT), U27.1 (DIN)
unnamed: U28.3 (DOUT), U29.1 (DIN)
unnamed: U29.3 (DOUT), U30.1 (DIN)
unnamed: U30.3 (DOUT), U31.1 (DIN)
unnamed: U31.3 (DOUT), U32.1 (DIN)
unnamed: U32.3 (DOUT), U33.1 (DIN)
unnamed: U33.3 (DOUT), U34.1 (DIN)
unnamed: U34.3 (DOUT), U35.1 (DIN)
unnamed: U35.3 (DOUT), U36.1 (DIN)
unnamed: U36.3 (DOUT), U37.1 (DIN)
unnamed: U37.3 (DOUT), U38.1 (DIN)
unnamed: U38.3 (DOUT), U39.1 (DIN)
unnamed: U40.3 (DOUT), U41.1 (DIN)
unnamed: U41.3 (DOUT), U42.1 (DIN)
unnamed: U42.3 (DOUT), U43.1 (DIN)
unnamed: U43.3 (DOUT), U44.1 (DIN)
unnamed: U44.3 (DOUT), U45.1 (DIN)
unnamed: U45.3 (DOUT), U46.1 (DIN)
unnamed: U46.3 (DOUT), U47.1 (DIN)
unnamed: U47.3 (DOUT), U48.1 (DIN)
unnamed: U48.3 (DOUT), U49.1 (DIN)
unnamed: U49.3 (DOUT), U50.1 (DIN)
unnamed: U50.3 (DOUT), U51.1 (DIN)
unnamed: U52.3 (DOUT), U53.1 (DIN)
unnamed: U53.3 (DOUT), U54.1 (DIN)
unnamed: U54.3 (DOUT), U55.1 (DIN)
unnamed: U55.3 (DOUT), U56.1 (DIN)
unnamed: U56.3 (DOUT), U57.1 (DIN)
unnamed: U57.3 (DOUT), U58.1 (DIN)
unnamed: U58.3 (DOUT), U59.1 (DIN)
unnamed: U59.3 (DOUT), U60.1 (DIN)
unnamed: U60.3 (DOUT), U61.1 (DIN)
unnamed: U61.3 (DOUT), U62.1 (DIN)
unnamed: U62.3 (DOUT), U63.1 (DIN)
unnamed: U64.3 (DOUT), U65.1 (DIN)
unnamed: U65.3 (DOUT), U66.1 (DIN)
unnamed: U66.3 (DOUT), U67.1 (DIN)
unnamed: U67.3 (DOUT), U68.1 (DIN)
unnamed: U68.3 (DOUT), U69.1 (DIN)
unnamed: U69.3 (DOUT), U70.1 (DIN)
unnamed: U70.3 (DOUT), U71.1 (DIN)
unnamed: U71.3 (DOUT), U72.1 (DIN)
unnamed: U72.3 (DOUT), U73.1 (DIN)
unnamed: U73.3 (DOUT), U74.1 (DIN)
unnamed: U74.3 (DOUT), U75.1 (DIN)
VCC: C1.2, C2.2, C3.2, C4.2, C5.1, U4.2 (VDD), U5.2 (VDD), U6.2 (VDD), U7.2 (VDD), U8.2 (VDD), U9.2 (VDD), U10.2 (VDD), U11.2 (VDD), U12.2 (VDD), U13.2 (VDD), U14.2 (VDD), U15.2 (VDD), U16.2 (VDD), U17.2 (VDD), U18.2 (VDD), U19.2 (VDD), U20.2 (VDD), U21.2 (VDD), U22.2 (VDD), U23.2 (VDD), U24.2 (VDD), U25.2 (VDD), U26.2 (VDD), U27.2 (VDD), U28.2 (VDD), U29.2 (VDD), U30.2 (VDD), U31.2 (VDD), U32.2 (VDD), U33.2 (VDD), U34.2 (VDD), U35.2 (VDD), U36.2 (VDD), U37.2 (VDD), U38.2 (VDD), U39.2 (VDD), U40.2 (VDD), U41.2 (VDD), U42.2 (VDD), U43.2 (VDD), U44.2 (VDD), U45.2 (VDD), U46.2 (VDD), U47.2 (VDD), U48.2 (VDD), U49.2 (VDD), U50.2 (VDD), U51.2 (VDD), U52.2 (VDD), U53.2 (VDD), U54.2 (VDD), U55.2 (VDD), U56.2 (VDD), U57.2 (VDD), U58.2 (VDD), U59.2 (VDD), U60.2 (VDD), U61.2 (VDD), U62.2 (VDD), U63.2 (VDD), U64.2 (VDD), U65.2 (VDD), U66.2 (VDD), U67.2 (VDD), U68.2 (VDD), U69.2 (VDD), U70.2 (VDD), U71.2 (VDD), U72.2 (VDD), U73.2 (VDD), U74.2 (VDD), U75.2 (VDD); also elsewhere on the board

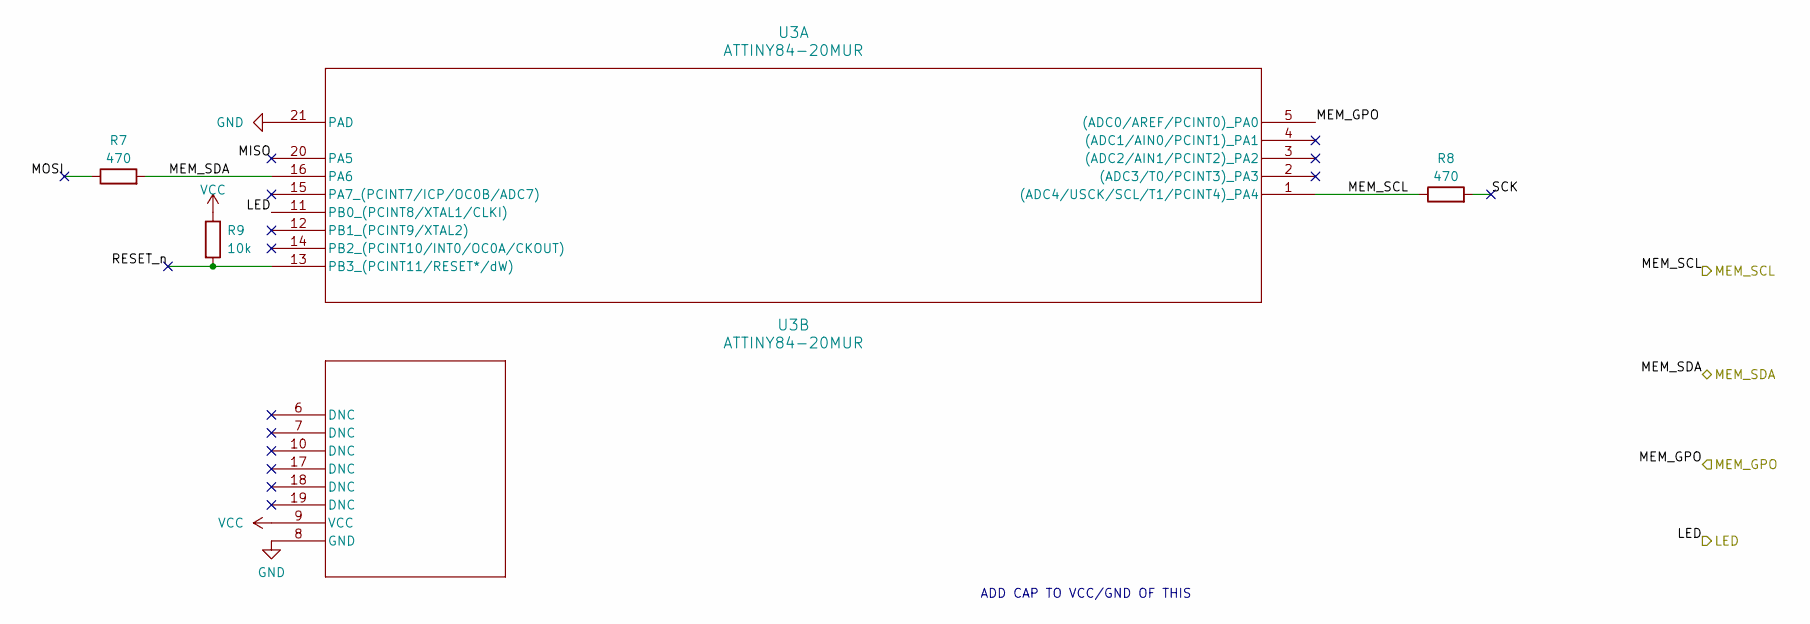
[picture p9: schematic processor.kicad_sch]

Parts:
R7, R8: 470; R_0603_1608Metric
R9: 10k; R_0603_1608Metric
U3: ATTINY84-20MUR; 20M1_ATM

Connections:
/Display/Processor/LED: U3.11 (PB0_(PCINT8/XTAL1/CLKI)); also elsewhere on the board
/Display/Processor/MISO: U3.20 (PA5); also elsewhere on the board
/Display/Processor/MOSI: R7.1; also elsewhere on the board
/Display/Processor/RESET_n: R9.2, U3.13 (PB3_(PCINT11/RESET*/dW)); also elsewhere on the board
/Display/Processor/SCK: R8.2; also elsewhere on the board
/NFC/NFC_GPO: U3.5 ((ADC0/AREF/PCINT0)_PA0); also elsewhere on the board
/NFC/NFC_SCL: R8.1, U3.1 ((ADC4/USCK/SCL/T1/PCINT4)_PA4); also elsewhere on the board
/NFC/NFC_SDA: R7.2, U3.16 (PA6); also elsewhere on the board
GND: U3.8 (GND), U3.21 (PAD); also elsewhere on the board
VCC: R9.1, U3.9 (VCC); also elsewhere on the board

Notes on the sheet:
ADD CAP TO VCC/GND OF THIS

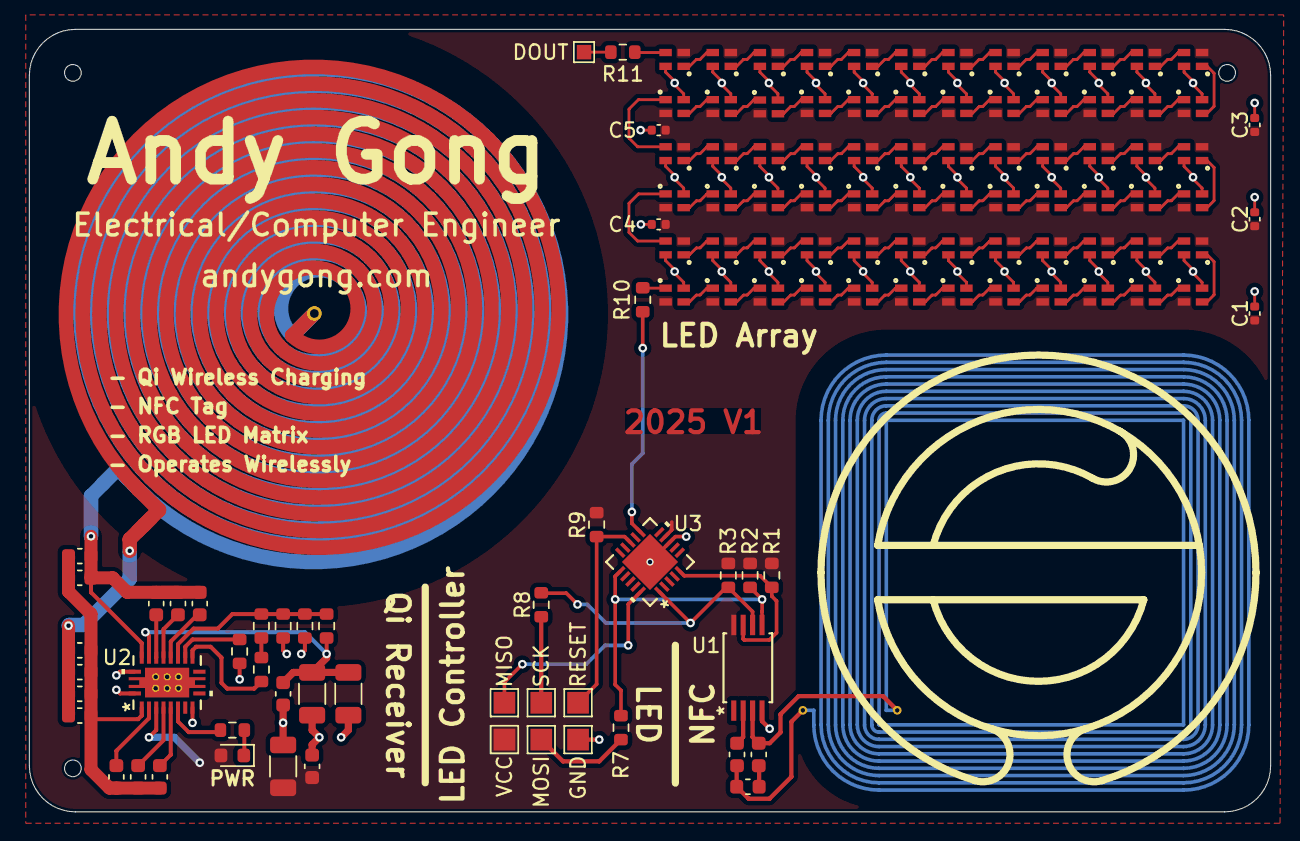
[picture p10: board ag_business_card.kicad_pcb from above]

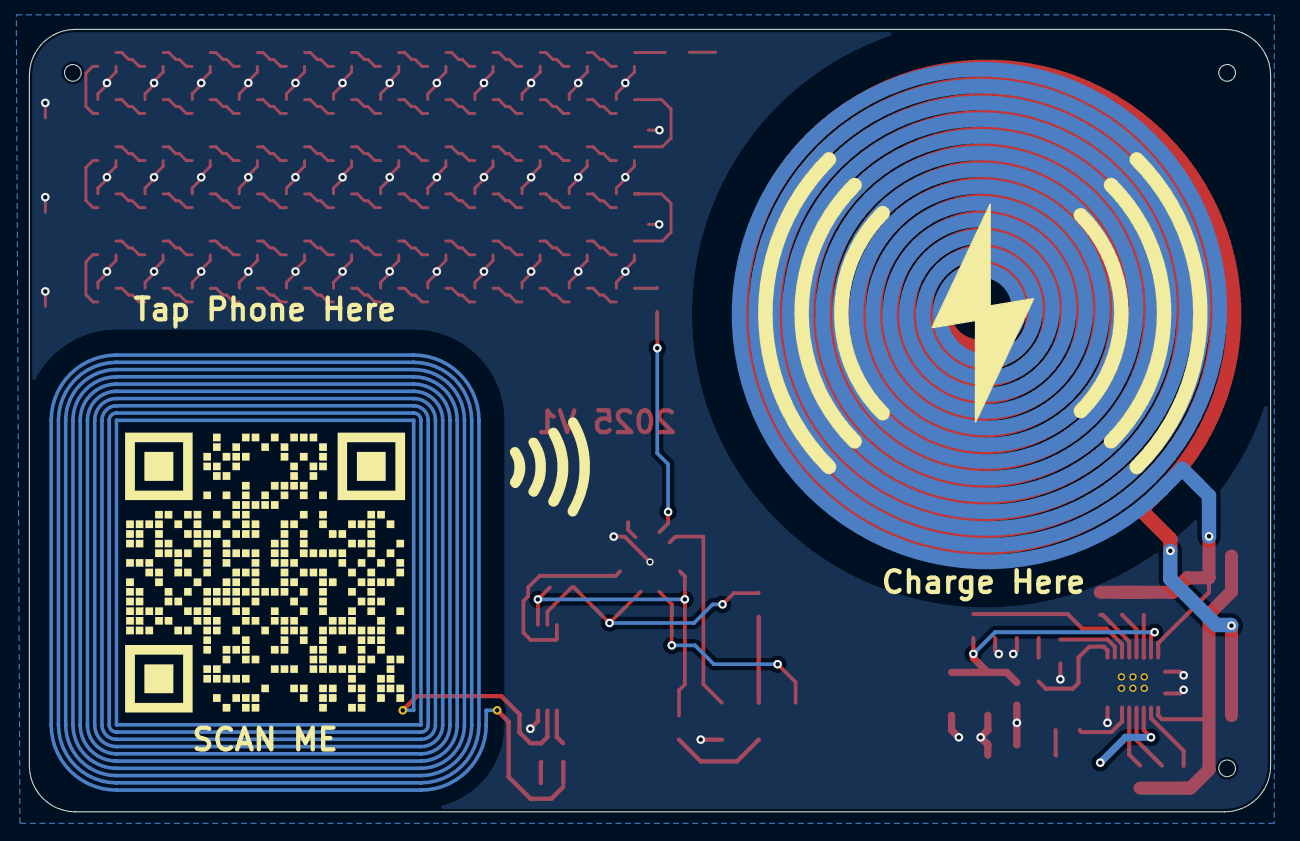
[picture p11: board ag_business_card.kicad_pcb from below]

Board: 2 copper layers, 85.6 x 54.0 mm, 126 parts (2 on the bottom side), 104 nets.

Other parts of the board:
DOUT: TestPoint_Pad_1.0x1.0mm
GND: TestPoint_Pad_1.5x1.5mm
MISO: TestPoint_Pad_1.5x1.5mm
MOSI: TestPoint_Pad_1.5x1.5mm
RESET: TestPoint_Pad_1.5x1.5mm
SCAN ME: LOGO; qr_code_bmp
SCK: TestPoint_Pad_1.5x1.5mm
VCC: TestPoint_Pad_1.5x1.5mm

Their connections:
/Display/LED Array/DOUT: DOUT.1; also elsewhere on the board
/Display/Processor/MISO: MISO.1; also elsewhere on the board
/Display/Processor/MOSI: MOSI.1; also elsewhere on the board
/Display/Processor/RESET_n: RESET.1; also elsewhere on the board
/Display/Processor/SCK: SCK.1; also elsewhere on the board
GND: GND.1; also elsewhere on the board
VCC: VCC.1; also elsewhere on the board

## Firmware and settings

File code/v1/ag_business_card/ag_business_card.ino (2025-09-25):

// AG Business Card 2025 V1 Processing Code
// This code reads the ST25DV64K NFC tag for display patterns, and displays them on the 6x12 RGB LED matrix. 

#include <Arduino.h>
#include <Wire.h>

// #################################################################################################################
// #                                      GLOBAL VARIABLES                                                         #
// #################################################################################################################

// LED matrix configuration
#define LED_PIN 10
#define LED_ROWS 6
#define LED_COLS 12

// NFC pin configuration
#define I2C_SDA 6
#define I2C_SCL 4
#define NFC_GPO 0

// NFC memory configuration
#define NFC_FIRST_ADDRESS 32 // The first address to read from the NFC tag, previous addresses are reserved for enabling url tap
#define NFC_MAX_POSSIBLE_FRAMES 627 // Max number of frames that can be stored on NFC tag
#define NFC_MAX_MEMORY_ADDRESS 8191 // Maximum address for ST25DV64K with 8kB of memory

// #################################################################################################################
// #                                      LED MATRIX FUNCTIONS                                                     #
// #################################################################################################################

// LED matrix defines
#define LED_COUNT (LED_ROWS * LED_COLS)
#define MAX_BRIGHTNESS 15 // Using 4-bit color depth (0-15) for each RGB channel, as power cannot supply 255,255,255 brightness for all LEDs
#define PIXEL_ARRAY_SIZE (LED_COUNT * 3 / 2) // 1.5 bytes per pixel (4 bits per channel, 3 channels per pixel, 12 bits per pixel)
#define NUM_PIXELS_IN_BYTES (LED_COUNT / 8) // Number of pixels, represented in bytes. For single_colour display mode
byte pixel_data[PIXEL_ARRAY_SIZE]; // GRB444 data format, 1.5 bytes per pixel (4 bits per channel, 3 channels per pixel, 12 bits per pixel)

// Variables for LED display (from the tinyNeoPixel_Static library)
uint32_t endTime = 0;
uint8_t p = LED_PIN;
volatile uint8_t *port;
uint8_t pinMask;
void leds_show() {
  /*
  This function sends the pixel_data stored into the RGB LED matrix.
  This function is similar to the `show()` function in the tinyNeoPixel library, but uses the static pixel_data array that only stores the lower 4 bits of each channel (upper bits are always 0).
  */
  while(!((micros() - endTime) >= 50L));

  // Initialize port and pinMask if not already done
  if (!port) {
    port = portOutputRegister(digitalPinToPort(p));
    pinMask = digitalPinToBitMask(p);
  }

  noInterrupts(); // Disable interrupts to ensure atomic operation

  volatile uint16_t i = PIXEL_ARRAY_SIZE; // Start count from number of bytes in the pixel_data array
  volatile uint8_t 
    *ptr = pixel_data, // Pointer to the pixel_data array
    b = *ptr++, // Read the first byte from the pixel_data array
    hi, lo; // PORT with output bit set high/low
  volatile uint8_t bit = 4; // Bit counter, starting from 4 (4 bits to write)

  volatile uint8_t n1, n2 = 0; // next bits out
  hi = (*port) | pinMask;
  lo = (*port) & ~pinMask; // Set the port to high and low states
  n1 = lo; // Assume first it out is 0
  if (b & 0x80) n1 = hi; // If first bit is 1, n1 = hi

  // Assembly to write the pixel data.
  // This code is structured as: HIGH, ZERO2LOW, ZERO2HIGH, LOW.
  // The order of execution is: ZERO2HIGH -> HIGH -> ZERO2LOW -> LOW -> ZERO2HIGH. 
  // This is to always write zeros in front of any 4 bits, and to allow the assembly size to fit within the rjmp instruction limit.
  asm volatile(
    "headD:"                  "\n\t" // Clk  Pseudocode
    "rjmp headzero2high"      "\n\t" // Jump to zero to high code as initialization
    // Write the upper 4 bits of a byte
    "headhigh4bits:"          "\n\t"
    // Bit 7: 1.25 us                // on target
    "st  %a[port] , %[hi]"    "\n\t" // 2   T = 2   PORT = hi   0 and 2
    "st  %a[port] , %[n1]"    "\n\t" // 2   T = 4   PORT = n1 - 250 ns zero
    "mov  %[n2]   , %[lo]"    "\n\t" // 1   T = 5   n2   = lo -
    "sbrc %[byte] , 6"        "\n\t" // 1-2 T = 6   if(b & 0x40)
     "mov %[n2]   , %[hi]"    "\n\t" // 0-1 T = 7   n2 = hi
    "st  %a[port] , %[lo]"    "\n\t" // 2   T = 9   PORT = lo
    "nop"                     "\n\t" // 1   T = 10  nop
    // Bit 6: 1.25 us                // on target
    "st  %a[port] , %[hi]"    "\n\t" // 2   T = 2   PORT = hi   0 and 2
    "st  %a[port] , %[n2]"    "\n\t" // 2   T = 4   PORT = n1 - 250 ns zero
    "mov  %[n1]   , %[lo]"    "\n\t" // 1   T = 5   n2   = lo -
    "sbrc %[byte] , 5"        "\n\t" // 1-2 T = 6   if(b & 0x20)
     "mov %[n1]   , %[hi]"    "\n\t" // 0-1 T = 7   n2 = hi
    "st  %a[port] , %[lo]"    "\n\t" // 2   T = 9   PORT = lo
    "nop"                     "\n\t" // 1   T = 10  nop
    // Bit 5: 1.25 us                // on target
    "st  %a[port] , %[hi]"    "\n\t" // 2   T = 2   PORT = hi   0 and 2
    "st  %a[port] , %[n1]"    "\n\t" // 2   T = 4   PORT = n1 - 250 ns zero
    "mov  %[n2]   , %[lo]"    "\n\t" // 1   T = 5   n2   = lo -
    "sbrc %[byte] , 4"        "\n\t" // 1-2 T = 6   if(b & 0x10)
     "mov %[n2]   , %[hi]"    "\n\t" // 0-1 T = 7   n2 = hi
    "st  %a[port] , %[lo]"    "\n\t" // 2   T = 9   PORT = lo
    "nop"                     "\n\t" // 1   T = 10  nop
    // Bit 4: 1.25 us                // on target
    "st  %a[port] , %[hi]"    "\n\t" // 2   T = 2   PORT = hi   0 and 2
    "st  %a[port] , %[n2]"    "\n\t" // 2   T = 4   PORT = n1 - 250 ns zero
    "mov  %[n1]   , %[lo]"    "\n\t" // 1   T = 5   n2   = lo -
    "sbrc %[byte] , 3"        "\n\t" // 1-2 T = 6   if(b & 0x08)
     "mov %[n1]   , %[hi]"    "\n\t" // 0-1 T = 7   n2 = hi
    "st  %a[port] , %[lo]"    "\n\t" // 2   T = 9   PORT = lo
    "nop"                     "\n\t" // 1   T = 10  nop
    // Write 4 zeros and jump to write lower 4 bits of the byte -- direct transition from writing upper 4 bits
    "headzero2low:"           "\n\t"
    // Zero Bit: 1.25 us             // on target
    "st  %a[port] , %[hi]"    "\n\t" // 2   T = 2   PORT = hi   0 and 2
    "st  %a[port] , %[lo]"    "\n\t" // 2   T = 4   PORT = lo - 250 ns zero
    "dec  %[bit]"             "\n\t" // 1   T = 5   bit--
    "breq zero2lowdone"       "\n\t" // 1-2 T = 6   Branch if bit == 0 (Z flag set)
    "nop"                     "\n\t" // 1   T = 7   nop
    "nop"                     "\n\t" // 1   T = 8   nop
    "rjmp headzero2low"       "\n\t" // 2   T = 10  Jump back to write zeros if bit is not zero
    "zero2lowdone:"           "\n\t" //     T = 7   Label for zero to low done
    "ldi  %[bit], 4"          "\n\t" // 1   T = 8   Reset bit counter to 4
    "rjmp headlow4bits"       "\n\t" // 2   T = 10  Jump to write lower 4 bits of the byte
    // Write 4 zeros and jump to write upper 4 bits of the byte
    "headzero2high:"          "\n\t"
    // Zero Bit: 1.25 us             // on target
    "st  %a[port] , %[hi]"    "\n\t" // 2   T = 2   PORT = hi   0 and 2
    "st  %a[port] , %[lo]"    "\n\t" // 2   T = 4   PORT = lo - 250 ns zero
    "dec  %[bit]"             "\n\t" // 1   T = 5   bit--
    "breq zero2highdone"      "\n\t" // 1-2 T = 6   Branch if bit == 0 (Z flag set)
    "nop"                     "\n\t" // 1   T = 7   nop
    "nop"                     "\n\t" // 1   T = 8   nop
    "rjmp headzero2high"      "\n\t" // 2   T = 10  Jump back to write zeros if bit is not zero
    "zero2highdone:"          "\n\t" //     T = 7   Label for zero to high done
    "ldi  %[bit], 4"          "\n\t" // 1   T = 8   Reset bit counter to 4
    "rjmp headhigh4bits"      "\n\t" // 2   T = 10  Jump to write higher 4 bits of the byte
    // Write the lower 4 bits of a byte
    "headlow4bits:"           "\n\t"
    // Bit 3: 1.25 us                // on target
    "st  %a[port] , %[hi]"    "\n\t" // 2   T = 2   PORT = hi   0 and 2
    "st  %a[port] , %[n1]"    "\n\t" // 2   T = 4   PORT = n1 - 250 ns zero
    "mov  %[n2]   , %[lo]"    "\n\t" // 1   T = 5   n2   = lo -
    "sbrc %[byte] , 2"        "\n\t" // 1-2 T = 6   if(b & 0x04)
     "mov %[n2]   , %[hi]"    "\n\t" // 0-1 T = 7   n2 = hi
    "st  %a[port] , %[lo]"    "\n\t" // 2   T = 9   PORT = lo
    "subi %A[count], 1"       "\n\t" // 1   T = 10  i-- part 1
    // Bit 2: 1.25 us                // on target
    "st  %a[port] , %[hi]"    "\n\t" // 2   T = 2   PORT = hi   0 and 2
    "st  %a[port] , %[n2]"    "\n\t" // 2   T = 4   PORT = n1 - 250 ns zero
    "mov  %[n1]   , %[lo]"    "\n\t" // 1   T = 5   n2   = lo -
    "sbrc %[byte] , 1"        "\n\t" // 1-2 T = 6   if(b & 0x02)
     "mov %[n1]   , %[hi]"    "\n\t" // 0-1 T = 7   n2 = hi
    "st  %a[port] , %[lo]"    "\n\t" // 2   T = 9   PORT = lo
    "sbci %B[count], 0"       "\n\t" // 1   T = 10  i-- part 2 - carrying clears 0 flag unless this is also 0. (don't act on Z flag yet)
    // Bit 1: 1.375 us               // 1 clock over
    "st  %a[port] , %[hi]"    "\n\t" // 2   T = 2   PORT = hi   0 and 2
    "st  %a[port] , %[n1]"    "\n\t" // 2   T = 4   PORT = n1 - 250 ns zero
    "mov  %[n2]   , %[lo]"    "\n\t" // 1   T = 5   n2   = lo -
    "sbrc %[byte] , 0"        "\n\t" // 1-2 T = 6   if(b & 0x01)
     "mov %[n2]   , %[hi]"    "\n\t" // 0-1 T = 7   n2 = hi
    "st  %a[port] , %[lo]"    "\n\t" // 2   T = 9   PORT = lo
    "ld   %[byte] , %a[ptr]+" "\n\t" // 2   T = 11  b = *ptr++ load next byte
    // Bit 0: 1.375 us               // 1 clock over
    "st   %a[port] , %[hi]"   "\n\t" // 2   T = 2   PORT = hi   0 and 2
    "st   %a[port] , %[n2]"   "\n\t" // 2   T = 4   PORT = n1 - 250 ns zero
    "mov  %[n1]   , %[lo]"    "\n\t" // 1   T = 5   n2   = lo -
    "sbrc %[byte] , 7"        "\n\t" // 1-2 T = 6   if(b & 0x80)
     "mov %[n1]   , %[hi]"    "\n\t" // 0-1 T = 7   n1 = hi
    "st   %a[port] , %[lo]"   "\n\t" // 2   T = 9   PORT = lo
    "brne headzero2high"      "\n"   // 2   T = 11  while(i) (Z flag set above)
  : [byte]  "+r" (b),
    [n1]    "+r" (n1),
    [n2]    "+r" (n2),
    [count] "+d" (i),
    [ptr]   "+e" (ptr),
    [bit]   "+r" (bit)
  : [port]   "e" (port),
    [hi]     "r" (hi),
    [lo]     "r" (lo));

  interrupts(); // Re-enable interrupts after the atomic operation
  endTime = micros();
}

// LED Utility Functions
uint8_t pixel_index;
uint8_t pixel_setter_pixel_index;
void leds_clear_matrix() {
  // Clear the LED matrix by setting all pixel data to zero, and show the update
  // This turns off all LEDs
  for (pixel_setter_pixel_index = 0; pixel_setter_pixel_index < PIXEL_ARRAY_SIZE; pixel_setter_pixel_index++) {
    pixel_data[pixel_setter_pixel_index] = 0; // Set all RGB values to 0
  }
  leds_show(); // Update the LED matrix to reflect the changes
}

void leds_set_pixel_color_by_coordinate(uint8_t x, uint8_t y, uint8_t r, uint8_t g, uint8_t b, byte *pixel_data) {
  // Set the color of a pixel at (x, y) position
  // Bottom-Left is (0, 0), top-right is (11, 5)
  // The LED matrix is ordered in a zigzag pattern: left-to-right on even rows, right-to-left on odd rows
  // The destination array can be pixel_data or any other byte array of size > PIXEL_ARRAY_SIZE
  if (x < LED_COLS && y < LED_ROWS) {
    pixel_setter_pixel_index = (y * LED_COLS + (y % 2 == 0 ? x : (LED_COLS - 1 - x))); // Calculate the index of the pixel's location
    if (pixel_setter_pixel_index % 2 != 0) {
      // If the pixel index is odd, then its first "G" channel is 2nd half of the first byte, and R/B channels are in the second byte
      pixel_setter_pixel_index = pixel_setter_pixel_index * 3 / 2;
      pixel_data[pixel_setter_pixel_index] &= 0xF0; // Clear the lower 4 bits of the first byte (G channel)
      pixel_data[pixel_setter_pixel_index] |= (g & 0x0F); // Set the lower 4 bits to G channel value
      pixel_data[pixel_setter_pixel_index + 1] = (r & 0x0F) << 4; // Set the upper 4 bits of the second byte to R channel value
      pixel_data[pixel_setter_pixel_index + 1] |= (b & 0x0F); // Set the lower 4 bits of the second byte to B channel value
    } else {
      // If the pixel index is even, then G/R channels are in the first byte, and B channel is in the second byte
      pixel_setter_pixel_index = pixel_setter_pixel_index * 3 / 2;
      pixel_data[pixel_setter_pixel_index] = (g & 0x0F) << 4; // Set the upper 4 bits of the first byte to G channel value
      pixel_data[pixel_setter_pixel_index] |= (r & 0x0F); // Set the lower 4 bits of the first byte to R channel value
      pixel_data[pixel_setter_pixel_index + 1] &= 0x0F; // Clear the upper 4 bits of the second byte (B channel)
      pixel_data[pixel_setter_pixel_index + 1] |= (b & 0x0F) << 4; // Set the upper 4 bits of the second byte to B channel value
    }
  }
}


void leds_set_pixel_color_by_index(uint8_t index, uint8_t r, uint8_t g, uint8_t b, byte *dest_buffer) {
  // Set the color of a pixel at the specified index
  // Index is from 0 to LED_COUNT - 1
  // The destination array can be pixel_data or any other byte array of size > PIXEL_ARRAY_SIZE
  if (index < LED_COUNT) {
    pixel_setter_pixel_index = (index * 3) / 2; // Calculate the index in the pixel_data array
    if (index % 2 != 0) {
      // If the index is odd, then its first "G" channel is 2nd half of the first byte, and R/B channels are in the second byte
      dest_buffer[pixel_setter_pixel_index] &= 0xF0; // Clear the lower 4 bits of the first byte (G channel)
      dest_buffer[pixel_setter_pixel_index] |= (g & 0x0F); // Set the lower 4 bits to G channel value
      dest_buffer[pixel_setter_pixel_index + 1] = ((r & 0x0F) << 4) & 0xF0; // Set the upper 4 bits of the second byte to R channel value
      dest_buffer[pixel_setter_pixel_index + 1] |= (b & 0x0F); // Set the lower 4 bits of the second byte to B channel value
    } else {
      // If the index is even, then G/R channels are in the first byte, and B channel is in the second byte
      dest_buffer[pixel_setter_pixel_index] = ((g & 0x0F) << 4) & 0xF0; // Set the upper 4 bits of the first byte to G channel value
      dest_buffer[pixel_setter_pixel_index] |= (r & 0x0F); // Set the lower 4 bits of the first byte to R channel value
      dest_buffer[pixel_setter_pixel_index + 1] &= 0x0F; // Clear the upper 4 bits of the second byte (B channel)
      dest_buffer[pixel_setter_pixel_index + 1] |= ((b & 0x0F) << 4) & 0xF0; // Set the upper 4 bits of the second byte to B channel value
    }
  }
}

void leds_fill_solid_red() {
  // Fill the entire LED matrix with solid red color. Always to the pixel_data array.
  for (pixel_setter_pixel_index = 0; pixel_setter_pixel_index < PIXEL_ARRAY_SIZE; pixel_setter_pixel_index += 3) {
    pixel_data[pixel_setter_pixel_index] = 0x0F; // Set G channel to 0, R channel to 15
    pixel_data[pixel_setter_pixel_index + 1] = 0x00; // Set B channel to 0
    pixel_data[pixel_setter_pixel_index + 2] = 0xF0; // Set R channel to 15, B channel to 0

  }
  leds_show(); // Update the LED matrix to reflect the changes
}

// #################################################################################################################
// #                                             NFC FUNCTIONS                                                     #
// #################################################################################################################

const int NFC_I2C_ADDRESS = 0b1010011; // ST25DV64K NFC tag I2C address
#define NFC_MAX_MEMORY_READ_LENGTH 30 // Maximum number of bytes that can be read from the NFC tag in one go
#define NFC_DATA_BUFFER_SIZE PIXEL_ARRAY_SIZE // Size of the buffer to store NFC data, should be enough for most frames

byte nfc_data[NFC_DATA_BUFFER_SIZE]; // Buffer for NFC data
byte nfc_address_upper_byte; // Upper byte of the NFC memory address
byte nfc_address_lower_byte; // Lower byte of the NFC memory address
int nfc_index; // Iterator for NFC data
int nfc_length_remaining;
int nfc_read_counter;

bool nfc_read_data(int address, int length) {
  /*
  This function reads data from the NFC tag at the specified memory address, and stores it in the nfc_data buffer.
  Parameters:
    - address: The memory address to read from (0-8191) for ST25DV64K with 8kB of memory.
    - length: The number of bytes to read (1-128), length of 0 will return false.
  Returns:
    - true if data was read successfully, false otherwise.
  */
  if (length <= 0 || address + length > NFC_MAX_MEMORY_ADDRESS || length > NFC_DATA_BUFFER_SIZE) return false; // Check if length is valid and does not exceed maximum address

  Wire.beginTransmission(NFC_I2C_ADDRESS); // Open I2C session with a write operation
  nfc_address_upper_byte = (address >> 8) & 0xFF; // Get upper byte of address
  nfc_address_lower_byte = address & 0xFF; // Get lower byte of address
  Wire.write(nfc_address_upper_byte); // Write upper address byte.
  Wire.write(nfc_address_lower_byte); // Write lower address byte
  if (Wire.endTransmission(false)) return false; // Do not release the bus, send RESTART condition. Return false if transmission failed (return value != 0)

  nfc_index = 0; // Reset the index for reading data
  nfc_length_remaining = length; // Set the remaining length to read
  while (nfc_length_remaining > NFC_MAX_MEMORY_READ_LENGTH) {
    // We have to read NFC_MAX_MEMORY_READ_LENGTH bytes at a time
    Wire.requestFrom(NFC_I2C_ADDRESS, NFC_MAX_MEMORY_READ_LENGTH); // Request data from NFC tag
    if (Wire.available() == NFC_MAX_MEMORY_READ_LENGTH) {
      for (nfc_read_counter = 0; nfc_read_counter < NFC_MAX_MEMORY_READ_LENGTH; nfc_read_counter++) {
        nfc_data[nfc_index++] = Wire.read(); // Read data into buffer
      }
      nfc_length_remaining -= NFC_MAX_MEMORY_READ_LENGTH; // Decrease the remaining length
    } else {
      return false; // Failed to read data
    }
  }
  // We can read the remaining data in one go
  Wire.requestFrom(NFC_I2C_ADDRESS, nfc_length_remaining); // Request remaining data from NFC tag
  if (Wire.available() == nfc_length_remaining) {
    for (nfc_read_counter = 0; nfc_read_counter < nfc_length_remaining; nfc_read_counter++) {
      nfc_data[nfc_index++] = Wire.read(); // Read data into buffer
    }
    return true; // Data read successfully
  } else {
    return false; // Failed to read data
  }
}

// #################################################################################################################
// #                                             UTIL FUNCTIONS                                                    #
// #################################################################################################################

void demo() {
  // Function flashes RGB through all pixels. Just to confirm that the LED matrix is working.
  leds_clear_matrix(); // Clear the LED matrix before starting
  for (pixel_index = 0; pixel_index < PIXEL_ARRAY_SIZE; pixel_index++) {
    // Set each pixel to a different color
    pixel_data[pixel_index] = 0xF0; // Set upper bits to 15
    leds_show(); // Show the update
    delay(5);
    pixel_data[pixel_index] = 0x0F; // Set lower bits to 15
    leds_show(); // Show the update
    delay(5);
    pixel_data[pixel_index] = 0x00; // Reset pixel to 0
  }
  leds_clear_matrix(); // Clear the LED matrix after the demo
}

// Global variables for storing the current state of the NFC tag and LED matrix
uint16_t num_frames = 0; // Variable to remember number of frames are stored in the NFC tag
byte color_mode = 0; // Only lowest 3 bits used for color mode. 0 = GRB444, rest from 001 to 111 are corresponding to GRB channel max brightness (e.g. 001 = B, 011 = R+B, 111 = R+G+B)
uint16_t transition_time = 0; // Transition time in milliseconds for the LED matrix pattern from the previous frame after it has finished displaying
uint16_t frame_duration = 0; // Duration in milliseconds for the LED matrix pattern to be displayed before transitioning to the next frame
uint16_t initial_delay = 0; // Initial delay in milliseconds before the first frame begins transitioning
int current_nfc_address = NFC_FIRST_ADDRESS; // Current NFC address to read from, starts at NFC_FIRST_ADDRESS

unsigned long start_time = 0; // Start time of the timer
unsigned long current_time = 0; // Current time in milliseconds

bool initialize() {
  /*
  This function runs at beginning of loop() to read the basic parameters from the NFC tag. 
  Reads the number of frames (stored in first 2 bytes)
  Reads the initial delay (stored in next 2 bytes)
  Clears the pixel data buffer
  Returns true if initialization was successful, false otherwise.
  */

  // demo(); // Run the demo to check if the LED matrix is working

  current_nfc_address = NFC_FIRST_ADDRESS;

  leds_clear_matrix(); // Clear the LED matrix before starting

  if (!nfc_read_data(current_nfc_address, 4)) {
    leds_fill_solid_red(); // Fill the LED matrix with solid red color to indicate error
    delay(500); // Wait for 500ms to indicate error
    return false; // Failed to read data from NFC tag
  }

  num_frames = (nfc_data[0] << 8) | nfc_data[1]; // Read number of frames from the first 2 bytes
  initial_delay = (nfc_data[2] << 8) | nfc_data[3]; // Read initial delay from the next 2 bytes

  current_nfc_address += 4; // Move to the next address for reading frame data

  delay(initial_delay); // Wait for the initial delay before starting to display frames

  return true; // Initialization successful
}
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
void loop() {
  if (!initialize()) {
    // If initialization failed, repeat loop(). initialize() have already filled the LED matrix with solid red color to indicate error
    return;
  }

  // If there are frames to display, start the display loop
  while (num_frames) {
    if (!load_and_display_frame()) {
      // If loading and displaying failed, break out of the loop and restart. 
      break;
    }
  }
}

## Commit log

2025-07-19 Add KiCad project files for V1 business card
    Added PCB layout, schematic, project, and symbol/footprint files for the AG Business Card V1, including display, NFC, Qi charger, and custom coil footprints. Also included a production ZIP archive fo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
    [ag_business_card.kicad_pcb, ag_business_card.kicad_sch, display.kicad_sch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]
2025-07-19 Restructure PCB files and add code placeholder
    Moved all KiCad PCB design files and related assets from the V1 directory to pcb/v1 for improved organization. Added a placeholder ag_business_card.ino file for Arduino code in code/v1/ag_business_ca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
    [ag_business_card.kicad_pcb, ag_business_card.kicad_sch, display.kicad_sch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]
2025-07-19 Rename V1 image files to lowercase filenames
    Renamed image files in img/v1/ to use lowercase filenames for consistency and to avoid potential case-sensitivity issues.
2025-07-19 Update README with revision history and images
    Added a major revisions section for V1 (2025) and included render and manufactured board images to improve documentation and showcase the PCB business card design.
2025-07-19 Move PCB zip to production directory
    Renamed Full_Card_V1_2025-07-13_21-04-21.zip from pcb/v1/ to pcb/v1/production/ for better organization of production files.
2025-07-19 Update README with new features and components
    Added details about Qi wireless charging, NFC tag support, RGB LED matrix, and fully wireless operation. Also included information on the BQ51013B power receiver, ST25DV64K NFC tag, and QR code funct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
2025-07-19 Update manufacturer info in README
    Clarified that JLCPCB both manufactured and assembled the product in the project documentation.
2025-07-20 Add initial AG Business Card V1 code and README
    Added a README with setup and requirements for the AG Business Card V1 project. Implemented initial Arduino code for the ATTiny84 to control a 6x12 RGB LED matrix and placeholder display patterns, wi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
2025-07-22 Limit LED brightness and add color cycling pattern
    Introduced MAX_BRIGHTNESS to prevent overpowering the LED matrix and replaced hardcoded brightness values with this constant. Added a new color cycling pattern to the LED display for enhanced visual effect.
    [ag_business_card.ino]
2025-07-22 Add LED matrix utility functions and 'AG' pattern
    Introduces utility functions for clearing the LED matrix and setting individual pixel colors, supporting a 6x12 matrix with zigzag wiring. Updates the loop to display a custom 'AG' pattern after the 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
2025-07-22 Add NFC read and display functionality to LED matrix
    Introduced NFC I2C read support and logic to display NFC data on the LED matrix. Refactored loop iteration to use a global variable and added a function to read 9 bytes from the NFC tag, mapping the 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
2025-07-22 Reduce LED brightness and simplify color cycling
    Lowered MAX_BRIGHTNESS from 63 to 15 to prevent overpowering the LEDs and adjusted the color cycling logic to match the new brightness range. This helps ensure safe operation and consistent color display across all LEDs.
    [ag_business_card.ino]
2025-07-22 Expand README with detailed hardware and encoding info
    Added comprehensive documentation on pin usage, LED matrix control, NFC I2C communication, and pattern encoding for the AG Business Card V1. The update includes explanations of memory optimizations, 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
2025-07-22 Refactor NFC I2C address variable and adjust delays
    Renamed NFC_ADDRESS to NFC_I2C_ADDRESS for clarity and updated all references. Reduced LED animation delay from 100ms to 10ms for faster visual feedback. Added clarification comment on bit order in N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
2025-07-22 Update README with NeoPixel library and bootloader info
    Added clarification about configuring the bootloader to use PORT B when using the tinyNeoPixel_Static library for the LED pin on ATTiny84.
2025-07-22 Add early code testing video and update README
    Added 'v1_early_test.mov' demonstrating simple patterns on the RGB LED Matrix, including an 'Among Us' pixel art pattern. Updated README to reference the video and provide context about the test and 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
2025-07-25 Update NFC I2C usage notes in README
    Added details about NFC tag password protection assumptions and initial 500 ms delay for tag power-up in the ATTiny84 startup sequence.
2025-07-25 Refactor LED matrix and NFC logic for frame-based display
    Reorganized code to support frame-based LED matrix animations loaded from NFC tag memory. Added functions for GRB444 and solid color frame display, transition handling, and improved pixel data management. Replaced placeholder loop logic with initialization and frame display routines, enabling dynamic patterns based on NFC data.
    [ag_business_card.ino]
2025-07-25 Add PCB business card project documentation
    Created docs/info.md to document the development procedures, research, and resources for the PCB business card project, including Qi charging, NFC tag, processor, and LED matrix design considerations.
2025-07-26 Expand design notes for NFC, processor, and LED matrix
    Added detailed explanations of design decisions and challenges for the NFC tag, processor selection, and LED matrix implementation. These notes provide more context on hardware choices, trade-offs, a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
2025-07-27 Set NFC address during initialization
    Assigns NFC_FIRST_ADDRESS to current_nfc_address at the start of the initialize() function to ensure proper NFC setup before proceeding.
2025-07-28 Implement smooth frame transition for LED matrix
    Replaced the previous buffer copy logic with a new transition algorithm that interpolates pixel values over time for smoother frame changes. Removed the unused leds_copy_from_buffer function and updated handle_transition to use direct memory copying and per-channel interpolation, improving visual effects during frame transitions.
    [ag_business_card.ino]
2025-07-28 Implement custom LED matrix display function
    Replaces tinyNeoPixel_Static library usage with a custom `leds_show()` function for sending pixel data to the RGB LED matrix. Adds low-level port manipulation and inline assembly for precise timing, tailored for the GRB444 data format and 6x12 LED matrix.
    [ag_business_card.ino]
2025-07-29 Refactor LED assembly and add demo function
    Refactored the assembly code in leds_show() to use a bit counter and more compact structure for writing pixel data, improving maintainability and fitting within instruction limits. Added a demo() fun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
2025-07-29 Remove unused variable 'pin' from LED display code
    The 'pin' variable was declared but not used in the LED display section. This cleanup removes the redundant variable to improve code clarity.
2025-07-29 Expand and clarify NFC LED matrix documentation
    Extended the README with detailed explanations of the assembly code structure, frame metadata, code flow, and variable/function documentation for the NFC-driven LED matrix project. Clarified the handling of frame transitions, error states, and provided a comprehensive overview of hardware configuration and data encoding.
2025-07-29 Update error handling and documentation for frame display
    Modified the error handling in the frame display loop to break and restart initialization on failure, instead of retrying indefinitely. Updated the README to clarify that the program restarts from initialization after an error to prevent NFC memory issues.
    [ag_business_card.ino]
2025-07-31 Improve NFC read function to handle large data
    Refactored the nfc_read_data function to read data from the NFC tag in chunks, supporting reads larger than the I2C buffer limit. Added constants for maximum read length and buffer size, and updated 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
2025-07-31 Add 500ms delay after LED error indication
    Inserted a 500ms delay after filling the LED matrix with solid red to indicate errors during NFC read and frame display operations. This provides clearer visual feedback for error states.
    [ag_business_card.ino]
2025-07-31 Refactor transition handling in frame display functions
    Changed handle_transition from returning a bool to void and updated display_frame_grb444 and display_frame_solid_color to remove transition failure handling and always return true. This simplifies the transition logic and assumes transitions always succeed.
    [ag_business_card.ino]
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2025-08-01 Fix bitmask logic and pixel color packing in LED functions
    Corrects the calculation of pixel_data array indices and ensures proper bit masking when setting color channel values. Also fixes the color_mode bitmask logic in display_frame_solid_color() to assign RGB channels correctly.
    [ag_business_card.ino]
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2025-09-25 Fixing #2 allowing single-color display mode
    Fixing #2. There are multiple causes. First is the repeated use of variable pixel_index, when iterating through the temp_pixel_data array, same value is also used inside the leds_set_pixel_color_by_inxes. Could have messed up index. Created a new variable for those functions to use. Second is that the handle_transition() function forgot to leds_show() if transition value is 0.
    [ag_business_card.ino]
2025-09-25 Shorten demo() duration
    Decreased the delay in the demo function from 25ms to 5ms to speed up the LED animation and make transitions appear smoother.
    [ag_business_card.ino]
2025-09-25 Comment out demo function in initialization
    The demo() function call used for testing the LED matrix has been commented out in the initialize() function. This prevents the demo from running during normal initialization.
    [ag_business_card.ino]
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
